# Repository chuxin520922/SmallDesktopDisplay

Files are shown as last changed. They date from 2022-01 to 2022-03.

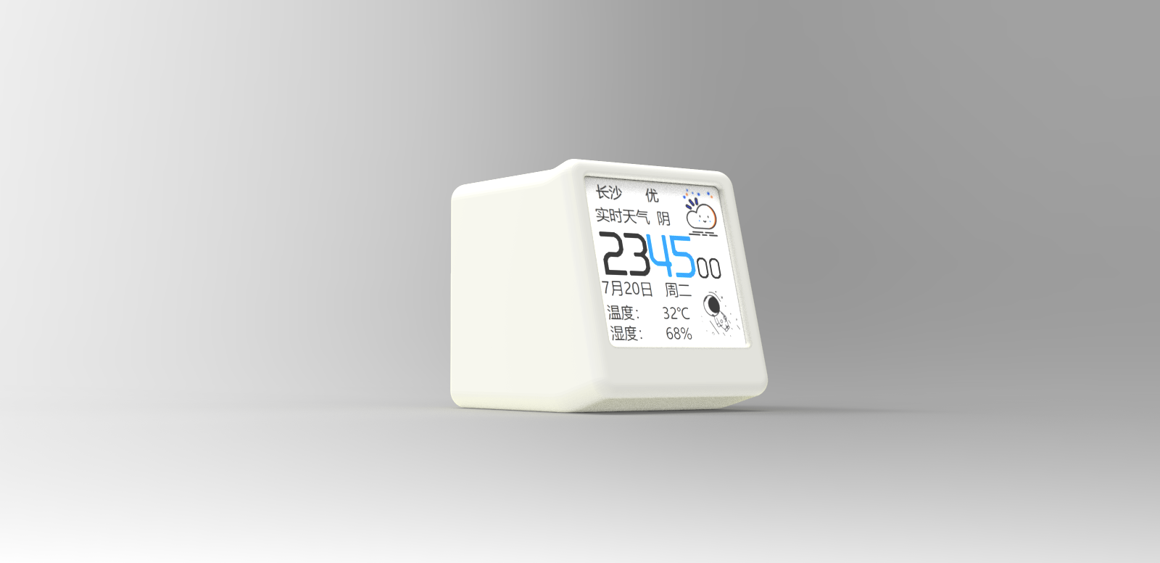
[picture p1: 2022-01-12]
1.Hardware/SD2-推荐桌面摆件/渲染图/渲染图2.png

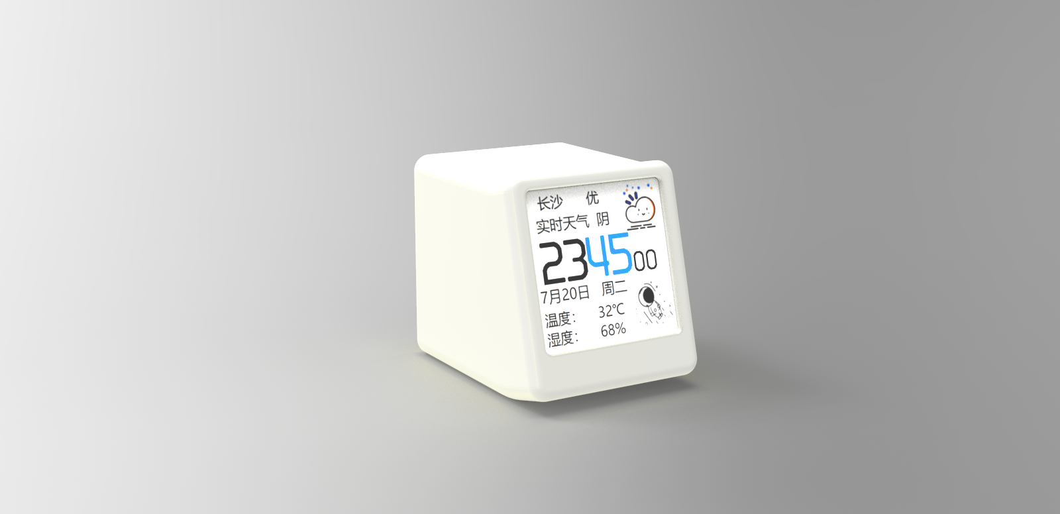
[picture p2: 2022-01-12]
1.Hardware/SD2-推荐桌面摆件/渲染图/渲染图3.png

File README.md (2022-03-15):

# SmallDesktopDisplay
# 沙雕系列-SD -太空人天气时钟显示

**视频介绍：** https://www.bilibili.com/video/BV1V64y1e72M/

## 1. 硬件打样说明

**PCB打样的话暂时没发现有啥需要特别注意的，注意附带的文件下单提示。** PCB文件可以直接拿去工厂打样，两层板很便宜，器件BOM的话也都是比较常用的。

`Hardware`文件内目前包含两个版本的PCB电路：

* **SD2-推荐桌面摆件** ：基于下面的版本轻微修改，将按键删去，无需按键，一键直达编译下载;新增了触摸扩展板，<code>IO口标识需要根据实际连接的改</code>
* **SD3-电脑主机显示** ：即视频中出现的版本，修改了PCB形状以适配新的外壳

**外壳加工** 根据自己喜欢的版本选择，`3D Model`文件夹目前包含2个版本的外壳文件：一 一 对 应文件即可

## 2. 固件编译说明

固件框架主要基于Arduino开发完成，玩过Arduino的基本没有上手难度了，把Firmware/Libraries里面的库安装到Arduino库目录（如果你用的是Arduino IDE的话）即可。

> 由于后续发现，使用的是VS code上面的PlatfromIO插件进行Arduino开发，因为VS code+PlatfromIO编译速度起飞，强烈推荐使用VS code+PlatfromIO来编译，大家可以选择自己喜欢的IDE就好了。
> 

**然后这里需要官方库文件才能正常使用：**

肯定得安装ESP83266的Arduino<code>**支持包2.6.3**</code>（百度也有海量教程，本文件已经附带安装包，直接安装即可）

**代码优化版本：VS code+PlatfromIO** https://github.com/SmallDesktopDisplay-team/SmallDesktopDisplay

## 3. QQ交流群

请注明来意！

官方群1：<code>811058758</code> （已满）

官方群2：<code>887171863</code>（已满）

官方群3：<code>477140920</code>（未满）

## 其他的后续再补充，有用的话记得点星星~

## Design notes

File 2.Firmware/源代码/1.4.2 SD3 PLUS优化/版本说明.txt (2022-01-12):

 * SmallDesktopDisplay
 *    小型桌面显示器
 * 
 * 原  作  者：Misaka
 * 修      改：微车游
 * 讨  论  群：811058758、887171863、720661626
 * 创 建 日 期：2021.07.19
 * 最后更改日期：2021.11.28
 * 更 改 说 明：V1.1添加串口调试，波特率115200\8\n\1；增加版本号显示。
 *            V1.2亮度和城市代码保存到EEPROM，断电可保存
 *            V1.3.1 更改smartconfig改为WEB配网模式，同时在配网的同时增加亮度、屏幕方向设置。
 *            V1.3.2 增加wifi休眠模式，仅在需要连接的情况下开启wifi，其他时间关闭wifi。增加wifi保存至eeprom（目前仅保存一组ssid和密码）
 *            V1.3.3  修改WiFi保存后无法删除的问题。目前更改为使用串口控制，输入 0x05 重置WiFi数据并重启。
 *                    增加web配网以及串口设置天气更新时间的功能。
 *            V1.3.4  修改web配网页面设置，将wifi设置页面以及其余设置选项放入同一页面中。
 *                    增加web页面设置是否使用DHT传感器。（使能DHT后才可使用）
 *             1.4.2  增加长按SD3 Plus底部按钮重置WiFi
 *                    基本汉化网页配置页面
 * 
 * 引 脚 分 配： SCK  GPIO14
 *             MOSI  GPIO13
 *             RES   GPIO2
 *             DC    GPIO0
 *             LCDBL GPIO5
 *             
 *             增加DHT11温湿度传感器，传感器接口为 GPIO 12
 * 
 *    感谢群友 @你别失望  提醒发现WiFi保存后无法重置的问题，目前已解决。详情查看更改说明！

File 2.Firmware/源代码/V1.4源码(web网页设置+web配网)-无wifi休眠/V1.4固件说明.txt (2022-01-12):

 SmallDesktopDisplay
    小型桌面显示器

原  作  者：Misaka
修      改：微车游
 
固件文件说明：
1、固件基本功能包含串口设置、web配网。详细说明请查看各个版本文件中的版本说明文件。
2、V1.4固件暂时只放出bin文件，考虑到可能还有bug。
3、V1.4版本重大更新：增加WEB设置页面，可以通过连接同一wifi下浏览器输入http://sd3.local，即可进行设置。

更 改 说 明：V1.1添加串口调试，波特率115200\8\n\1；增加版本号显示。
 *            V1.2亮度和城市代码保存到EEPROM，断电可保存
 *            V1.3.1 更改smartconfig改为WEB配网模式，同时在配网的同时增加亮度、屏幕方向设置。
 *            V1.3.2 增加wifi休眠模式，仅在需要连接的情况下开启wifi，其他时间关闭wifi。增加wifi保存至eeprom（目前仅保存一组ssid和密码）
 *            V1.3.3  修改WiFi保存后无法删除的问题。目前更改为使用串口控制，输入 0x05 重置WiFi数据并重启。
 *                    增加web配网以及串口设置天气更新时间的功能。
 *            V1.3.4  修改web配网页面设置，将wifi设置页面以及其余设置选项放入同一页面中。
 *                    增加web页面设置是否使用DHT传感器。（使能DHT后才可使用）
 *            V1.4    增加web服务器，使用web网页进行设置。由于使用了web服务器，无法开启WiFi休眠。
	         注意，此版本中的DHT11传感器和太空人图片选择可以通过web网页设置来进行选择，无需通过使能标志来重新编译。

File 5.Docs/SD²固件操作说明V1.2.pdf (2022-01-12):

# --------------- SD²固件操作指南------

# 更新日志：

# V1.0：初始程序 V1.1：增加了串口设置亮度、地址的功能 V1.2：亮度和城市代码保存到 EEPROM，断电可保存

# --------------- SD²固件操作指南------

# 一、 联网设置 1、将设备上电，电源输入规格为 5V； 2、等待联网进度条流过，会出现联网二维码； 3、使用手机微信扫码，扫码前请确认手机已连接至路由器的 2.4G WiFi 网

| 络，（MIUI12 需手动打开位置获取）；

# 4、按手机提示输入 WiFi 密码，点击配网。

# 注：有时候一次连接不成功，请多试几次；第一次联网后时间会大概率显示 不对，断电重启即可。地址根据 IP 地址获得，某些运营商网络可能出现地址 漂移等状况，请手动修改。

# 二、 串口设置(仅适用于 SD²V1.1 以上软件版本) 1、确保电脑已安装 CH340 驱动，打开串口软件； 2、将串口设置为 115200\8\n\1，如图；

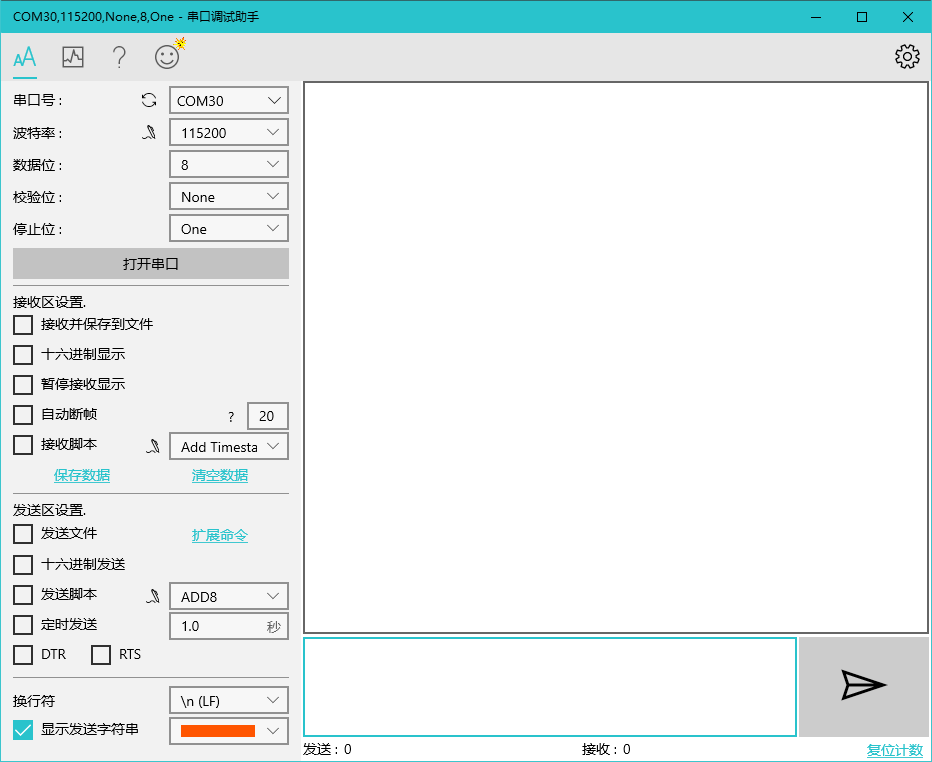
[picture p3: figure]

# 3、点击打开串口； 4、随便发送数据至设备；会回复操作说明，如图； 5、按操作说明输入控制代码即可，如图；

# --------------- SD²固件操作指南------

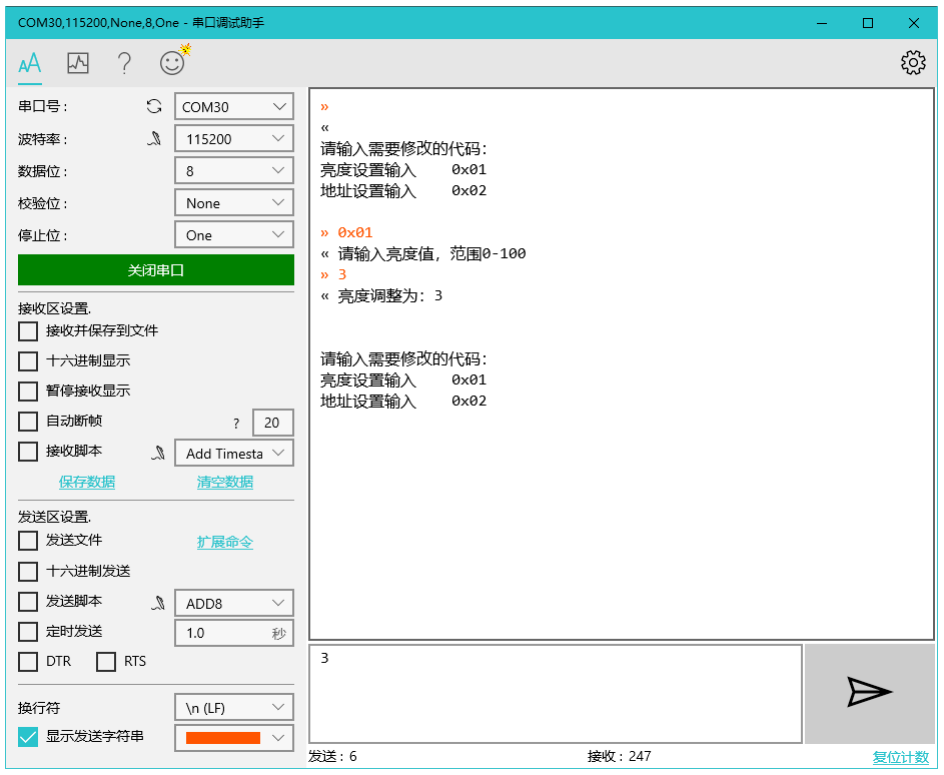
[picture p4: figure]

# 注：城市代码见附件。

# By Misaka

# --------------- SD²固件操作指南------

# 附件：城市代码 Ctrl+F 查找

"北京"=>"101010100","海淀"=>"101010200","朝阳"=>"101010300","顺义"=>"101010400","怀柔"=>"101010500","通州"=>"101010600","昌平

"=>"101010700","延庆"=>"101010800","丰台"=>"101010900","石景山"=>"101011000","大兴"=>"101011100","房山"=>"101011200","密云

"=>"101011300","门头沟"=>"101011400","平谷"=>"101011500","八达岭"=>"101011600","佛爷顶"=>"101011700","汤河口"=>"101011800","密

云上甸子"=>"101011900","斋堂"=>"101012000","霞云岭"=>"101012100",

"上海"=>"101020100","闵行"=>"101020200","宝山"=>"101020300","川沙"=>"101020400","嘉定"=>"101020500","南汇"=>"101020600","金山

"=>"101020700","青浦"=>"101020800","松江"=>"101020900","奉贤"=>"101021000","崇明"=>"101021100","陈家镇"=>"101021101","引水船

"=>"101021102","徐家汇"=>"101021200","浦东"=>"101021300",

"天津"=>"101030100","武清"=>"101030200","宝坻"=>"101030300","东丽"=>"101030400","西青"=>"101030500","北辰"=>"101030600","宁河

"=>"101030700","汉沽"=>"101030800","静海"=>"101030900","津南"=>"101031000","塘沽"=>"101031100","大港"=>"101031200","平台

"=>"101031300","蓟县"=>"101031400",

"重庆"=>"101040100","永川"=>"101040200","合川"=>"101040300","南川"=>"101040400","江津"=>"101040500","万盛"=>"101040600","渝北

"=>"101040700","北碚"=>"101040800","巴南"=>"101040900","长寿"=>"101041000","黔江"=>"101041100","万州天城"=>"101041200","万州龙

宝"=>"101041300","涪陵"=>"101041400","开县"=>"101041500","城口"=>"101041600","云阳"=>"101041700","巫溪"=>"101041800","奉节

"=>"101041900","巫山"=>"101042000","潼南"=>"101042100","垫江"=>"101042200","梁平"=>"101042300","忠县"=>"101042400","石柱

"=>"101042500","大足"=>"101042600","荣昌"=>"101042700","铜梁"=>"101042800","璧山"=>"101042900","丰都"=>"101043000","武隆

"=>"101043100","彭水"=>"101043200","綦江"=>"101043300","酉阳"=>"101043400","金佛山"=>"101043500","秀山"=>"101043600","沙坪坝

"=>"101043700",

"哈尔滨"=>"101050101","双城"=>"101050102","呼兰"=>"101050103","阿城"=>"101050104","宾县"=>"101050105","依兰"=>"101050106","巴彦

"=>"101050107","通河"=>"101050108","方正"=>"101050109","延寿"=>"101050110","尚志"=>"101050111","五常"=>"101050112","木兰

"=>"101050113","齐齐哈尔"=>"101050201","讷河"=>"101050202","龙江"=>"101050203","甘南"=>"101050204","富裕"=>"101050205","依安

"=>"101050206","拜泉"=>"101050207","克山"=>"101050208","克东"=>"101050209","泰来"=>"101050210","牡丹江"=>"101050301","海林

"=>"101050302","穆棱"=>"101050303","林口"=>"101050304","绥芬河"=>"101050305","宁安"=>"101050306","东宁"=>"101050307","佳木斯

"=>"101050401","汤原"=>"101050402","抚远"=>"101050403","桦川"=>"101050404","桦南"=>"101050405","同江"=>"101050406","富锦

"=>"101050407","绥化"=>"101050501","肇东"=>"101050502","安达"=>"101050503","海伦"=>"101050504","明水"=>"101050505","望奎

"=>"101050506","兰西"=>"101050507","青冈"=>"101050508","庆安"=>"101050509","绥棱"=>"101050510","黑河"=>"101050601","嫩江

"=>"101050602","孙吴"=>"101050603","逊克"=>"101050604","五大连池"=>"101050605","北安"=>"101050606","大兴安岭"=>"101050701","塔

河"=>"101050702","漠河"=>"101050703","呼玛"=>"101050704","呼中"=>"101050705","新林"=>"101050706","阿木尔"=>"101050707","加格达

奇"=>"101050708","伊春"=>"101050801","乌伊岭"=>"101050802","五营"=>"101050803","铁力"=>"101050804","嘉荫"=>"101050805","大庆

"=>"101050901","林甸"=>"101050902","肇州"=>"101050903","肇源"=>"101050904","杜蒙"=>"101050905","七台河"=>"101051002","勃利

"=>"101051003","鸡西"=>"101051101","虎林"=>"101051102","密山"=>"101051103","鸡东"=>"101051104","鹤岗"=>"101051201","绥滨

"=>"101051202","萝北"=>"101051203","双鸭山"=>"101051301","集贤"=>"101051302","宝清"=>"101051303","饶河"=>"101051304",

"长春"=>"101060101","农安"=>"101060102","德惠"=>"101060103","九台"=>"101060104","榆树"=>"101060105","双阳"=>"101060106","吉林

"=>"101060201","舒兰"=>"101060202","永吉"=>"101060203","蛟河"=>"101060204","磐石"=>"101060205","桦甸"=>"101060206","烟筒山

"=>"101060207","延吉"=>"101060301","敦化"=>"101060302","安图"=>"101060303","汪清"=>"101060304","和龙"=>"101060305","天池

# --------------- SD²固件操作指南------

"=>"101060306","龙井"=>"101060307","珲春"=>"101060308","图们"=>"101060309","松江"=>"101060310","罗子沟"=>"101060311","延边

"=>"101060312","四平"=>"101060401","双辽"=>"101060402","梨树"=>"101060403","公主岭"=>"101060404","伊通"=>"101060405","孤家子

"=>"101060406","通化"=>"101060501","梅河口"=>"101060502","柳河"=>"101060503","辉南"=>"101060504","集安"=>"101060505","通化县

"=>"101060506","白城"=>"101060601","洮南"=>"101060602","大安"=>"101060603","镇赉"=>"101060604","通榆"=>"101060605","辽源

"=>"101060701","东丰"=>"101060702","松原"=>"101060801","乾安"=>"101060802","前郭"=>"101060803","长岭"=>"101060804","扶余

"=>"101060805","白山"=>"101060901","靖宇"=>"101060902","临江"=>"101060903","东岗"=>"101060904","长白"=>"101060905",

"沈阳"=>"101070101","苏家屯"=>"101070102","辽中"=>"101070103","康平"=>"101070104","法库"=>"101070105","新民"=>"101070106","于洪

"=>"101070107","新城子"=>"101070108","大连"=>"101070201","瓦房店"=>"101070202","金州"=>"101070203","普兰店"=>"101070204","旅顺

"=>"101070205","长海"=>"101070206","庄河"=>"101070207","皮口"=>"101070208","海洋岛"=>"101070209","鞍山"=>"101070301","台安

"=>"101070302","岫岩"=>"101070303","海城"=>"101070304","抚顺"=>"101070401","清原"=>"101070403","章党"=>"101070404","本溪

"=>"101070501","本溪县"=>"101070502","草河口"=>"101070503","桓仁"=>"101070504","丹东"=>"101070601","凤城"=>"101070602","宽甸

"=>"101070603","东港"=>"101070604","东沟"=>"101070605","锦州"=>"101070701","凌海"=>"101070702","北宁"=>"101070703","义县

"=>"101070704","黑山"=>"101070705","北镇"=>"101070706","营口"=>"101070801","大石桥"=>"101070802","盖州"=>"101070803","阜新

"=>"101070901","彰武"=>"101070902","辽阳"=>"101071001","辽阳县"=>"101071002","灯塔"=>"101071003","铁岭"=>"101071101","开原

"=>"101071102","昌图"=>"101071103","西丰"=>"101071104","朝阳"=>"101071201","建平"=>"101071202","凌源"=>"101071203","喀左

"=>"101071204","北票"=>"101071205","羊山"=>"101071206","建平县"=>"101071207","盘锦"=>"101071301","大洼"=>"101071302","盘山

"=>"101071303","葫芦岛"=>"101071401","建昌"=>"101071402","绥中"=>"101071403","兴城"=>"101071404",

"呼和浩特"=>"101080101","土默特左旗"=>"101080102","托克托"=>"101080103","和林格尔"=>"101080104","清水河"=>"101080105","呼和浩特

市郊区"=>"101080106","武川"=>"101080107","包头"=>"101080201","白云鄂博"=>"101080202","满都拉"=>"101080203","土默特右旗

"=>"101080204","固阳"=>"101080205","达尔罕茂明安联合旗"=>"101080206","石拐"=>"101080207","乌海"=>"101080301","集宁

"=>"101080401","卓资"=>"101080402","化德"=>"101080403","商都"=>"101080404","希拉穆仁"=>"101080405","兴和"=>"101080406","凉城

"=>"101080407","察哈尔右翼前旗"=>"101080408","察哈尔右翼中旗"=>"101080409","察哈尔右翼后旗"=>"101080410","四子王旗

"=>"101080411","丰镇"=>"101080412","通辽"=>"101080501","舍伯吐"=>"101080502","科尔沁左翼中旗"=>"101080503","科尔沁左翼后旗

"=>"101080504","青龙山"=>"101080505","开鲁"=>"101080506","库伦旗"=>"101080507","奈曼旗"=>"101080508","扎鲁特旗"=>"101080509","

高力板"=>"101080510","巴雅尔吐胡硕"=>"101080511","通辽钱家店"=>"101080512","赤峰"=>"101080601","赤峰郊区站"=>"101080602","阿鲁

科尔沁旗"=>"101080603","浩尔吐"=>"101080604","巴林左旗"=>"101080605","巴林右旗"=>"101080606","林西"=>"101080607","克什克腾旗

"=>"101080608","翁牛特旗"=>"101080609","岗子"=>"101080610","喀喇沁旗"=>"101080611","八里罕"=>"101080612","宁城"=>"101080613","

敖汉旗"=>"101080614","宝过图"=>"101080615","鄂尔多斯"=>"101080701","达拉特旗"=>"101080703","准格尔旗"=>"101080704","鄂托克前旗

"=>"101080705","河南"=>"101080706","伊克乌素"=>"101080707","鄂托克旗"=>"101080708","杭锦旗"=>"101080709","乌审旗

"=>"101080710","伊金霍洛旗"=>"101080711","乌审召"=>"101080712","东胜"=>"101080713","临河"=>"101080801","五原"=>"101080802","磴

口"=>"101080803","乌拉特前旗"=>"101080804","大佘太"=>"101080805","乌拉特中旗"=>"101080806","乌拉特后旗"=>"101080807","海力素

"=>"101080808","那仁宝力格"=>"101080809","杭锦后旗"=>"101080810","巴盟农试站"=>"101080811","锡林浩特"=>"101080901","朝克乌拉

"=>"101080902","二连浩特"=>"101080903","阿巴嘎旗"=>"101080904","伊和郭勒"=>"101080905","苏尼特左旗"=>"101080906","苏尼特右旗

"=>"101080907","朱日和"=>"101080908","东乌珠穆沁旗"=>"101080909","西乌珠穆沁旗"=>"101080910","太仆寺旗"=>"101080911","镶黄旗

"=>"101080912","正镶白旗"=>"101080913","正兰旗"=>"101080914","多伦"=>"101080915","博克图"=>"101080916","乌拉盖"=>"101080917","

白日乌拉"=>"101080918","那日图"=>"101080919","呼伦贝尔"=>"101081000","海拉尔"=>"101081001","小二沟"=>"101081002","阿荣旗

"=>"101081003","莫力达瓦旗"=>"101081004","鄂伦春旗"=>"101081005","鄂温克旗"=>"101081006","陈巴尔虎旗"=>"101081007","新巴尔虎左

旗"=>"101081008","新巴尔虎右旗"=>"101081009","满洲里"=>"101081010","牙克石"=>"101081011","扎兰屯"=>"101081012","额尔古纳

"=>"101081014","根河"=>"101081015","图里河"=>"101081016","乌兰浩特"=>"101081101","阿尔山"=>"101081102","科尔沁右翼中旗

# --------------- SD²固件操作指南------

"=>"101081103","胡尔勒"=>"101081104","扎赉特旗"=>"101081105","索伦"=>"101081106","突泉"=>"101081107","霍林郭勒"=>"101081108","

阿拉善左旗"=>"101081201","阿拉善右旗"=>"101081202","额济纳旗"=>"101081203","拐子湖"=>"101081204","吉兰太"=>"101081205","锡林高

勒"=>"101081206","头道湖"=>"101081207","中泉子"=>"101081208","巴彦诺尔贡"=>"101081209","雅布赖"=>"101081210","乌斯太

"=>"101081211","孪井滩"=>"101081212",

"石家庄"=>"101090101","井陉"=>"101090102","正定"=>"101090103","栾城"=>"101090104","行唐"=>"101090105","灵寿"=>"101090106","高邑

"=>"101090107","深泽"=>"101090108","赞皇"=>"101090109","无极"=>"101090110","平山"=>"101090111","元氏"=>"101090112","赵县

"=>"101090113","辛集"=>"101090114","藁城"=>"101090115","晋洲"=>"101090116","新乐"=>"101090117","保定"=>"101090201","满城

"=>"101090202","阜平"=>"101090203","徐水"=>"101090204","唐县"=>"101090205","高阳"=>"101090206","容城"=>"101090207","紫荆关

"=>"101090208","涞源"=>"101090209","望都"=>"101090210","安新"=>"101090211","易县"=>"101090212","涞水"=>"101090213","曲阳

"=>"101090214","蠡县"=>"101090215","顺平"=>"101090216","雄县"=>"101090217","涿州"=>"101090218","定州"=>"101090219","安国

"=>"101090220","高碑店"=>"101090221","张家口"=>"101090301","宣化"=>"101090302","张北"=>"101090303","康保"=>"101090304","沽源

"=>"101090305","尚义"=>"101090306","蔚县"=>"101090307","阳原"=>"101090308","怀安"=>"101090309","万全"=>"101090310","怀来

"=>"101090311","涿鹿"=>"101090312","赤城"=>"101090313","崇礼"=>"101090314","承德"=>"101090402","承德县"=>"101090403","兴隆

"=>"101090404","平泉"=>"101090405","滦平"=>"101090406","隆化"=>"101090407","丰宁"=>"101090408","宽城"=>"101090409","围场

"=>"101090410","塞罕坎"=>"101090411","唐山"=>"101090501","丰南"=>"101090502","丰润"=>"101090503","滦县"=>"101090504","滦南

"=>"101090505","乐亭"=>"101090506","迁西"=>"101090507","玉田"=>"101090508","唐海"=>"101090509","遵化"=>"101090510","迁安

"=>"101090511","廊坊"=>"101090601","固安"=>"101090602","永清"=>"101090603","香河"=>"101090604","大城"=>"101090605","文安

"=>"101090606","大厂"=>"101090607","霸州"=>"101090608","三河"=>"101090609","沧州"=>"101090701","青县"=>"101090702","东光

"=>"101090703","海兴"=>"101090704","盐山"=>"101090705","肃宁"=>"101090706","南皮"=>"101090707","吴桥"=>"101090708","献县

"=>"101090709","孟村"=>"101090710","泊头"=>"101090711","任丘"=>"101090712","黄骅"=>"101090713","河间"=>"101090714","曹妃甸

"=>"101090715","衡水"=>"101090801","枣强"=>"101090802","武邑"=>"101090803","武强"=>"101090804","饶阳"=>"101090805","安平

"=>"101090806","故城"=>"101090807","景县"=>"101090808","阜城"=>"101090809","冀州"=>"101090810","深州"=>"101090811","邢台

"=>"101090901","临城"=>"101090902","邢台县浆水"=>"101090903","内邱"=>"101090904","柏乡"=>"101090905","隆尧"=>"101090906","南和

"=>"101090907","宁晋"=>"101090908","巨鹿"=>"101090909","新河"=>"101090910","广宗"=>"101090911","平乡"=>"101090912","威县

"=>"101090913","清河"=>"101090914","临西"=>"101090915","南宫"=>"101090916","沙河"=>"101090917","任县"=>"101090918","邯郸

"=>"101091001","峰峰"=>"101091002","临漳"=>"101091003","成安"=>"101091004","大名"=>"101091005","涉县"=>"101091006","磁县

"=>"101091007","肥乡"=>"101091008","永年"=>"101091009","邱县"=>"101091010","鸡泽"=>"101091011","广平"=>"101091012","馆陶

"=>"101091013","魏县"=>"101091014","曲周"=>"101091015","武安"=>"101091016","秦皇岛"=>"101091101","青龙"=>"101091102","昌黎

"=>"101091103","抚宁"=>"101091104","卢龙"=>"101091105","北戴河"=>"101091106",

"太原"=>"101100101","清徐"=>"101100102","阳曲"=>"101100103","娄烦"=>"101100104","太原古交区"=>"101100105","太原北郊

"=>"101100106","太原南郊"=>"101100107","大同"=>"101100201","阳高"=>"101100202","大同县"=>"101100203","天镇"=>"101100204","广灵

"=>"101100205","灵邱"=>"101100206","浑源"=>"101100207","左云"=>"101100208","阳泉"=>"101100301","盂县"=>"101100302","平定

"=>"101100303","晋中"=>"101100401","榆次"=>"101100402","榆社"=>"101100403","左权"=>"101100404","和顺"=>"101100405","昔阳

"=>"101100406","寿阳"=>"101100407","太谷"=>"101100408","祁县"=>"101100409","平遥"=>"101100410","灵石"=>"101100411","介休

"=>"101100412","长治"=>"101100501","黎城"=>"101100502","屯留"=>"101100503","潞城"=>"101100504","襄垣"=>"101100505","平顺

"=>"101100506","武乡"=>"101100507","沁县"=>"101100508","长子"=>"101100509","沁源"=>"101100510","壶关"=>"101100511","晋城

"=>"101100601","沁水"=>"101100602","阳城"=>"101100603","陵川"=>"101100604","高平"=>"101100605","临汾"=>"101100701","曲沃

"=>"101100702","永和"=>"101100703","隰县"=>"101100704","大宁"=>"101100705","吉县"=>"101100706","襄汾"=>"101100707","蒲县

"=>"101100708","汾西"=>"101100709","洪洞"=>"101100710","霍州"=>"101100711","乡宁"=>"101100712","翼城"=>"101100713","侯马

# --------------- SD²固件操作指南------

"=>"101100714","浮山"=>"101100715","安泽"=>"101100716","古县"=>"101100717","运城"=>"101100801","临猗"=>"101100802","稷山

"=>"101100803","万荣"=>"101100804","河津"=>"101100805","新绛"=>"101100806","绛县"=>"101100807","闻喜"=>"101100808","垣曲

"=>"101100809","永济"=>"101100810","芮城"=>"101100811","夏县"=>"101100812","平陆"=>"101100813","朔州"=>"101100901","平鲁

"=>"101100902","山阴"=>"101100903","右玉"=>"101100904","应县"=>"101100905","怀仁"=>"101100906","忻州"=>"101101001","定襄

"=>"101101002","五台县豆村"=>"101101003","河曲"=>"101101004","偏关"=>"101101005","神池"=>"101101006","宁武"=>"101101007","代县

"=>"101101008","繁峙"=>"101101009","五台山"=>"101101010","保德"=>"101101011","静乐"=>"101101012","岢岚"=>"101101013","五寨

"=>"101101014","原平"=>"101101015","吕梁"=>"101101100","离石"=>"101101101","临县"=>"101101102","兴县"=>"101101103","岚县

"=>"101101104","柳林"=>"101101105","石楼"=>"101101106","方山"=>"101101107","交口"=>"101101108","中阳"=>"101101109","孝义

"=>"101101110","汾阳"=>"101101111","文水"=>"101101112","交城"=>"101101113",

"西安"=>"101110101","长安"=>"101110102","临潼"=>"101110103","蓝田"=>"101110104","周至"=>"101110105","户县"=>"101110106","高陵

"=>"101110107","杨凌"=>"101110108","咸阳"=>"101110200","三原"=>"101110201","礼泉"=>"101110202","永寿"=>"101110203","淳化

"=>"101110204","泾阳"=>"101110205","武功"=>"101110206","乾县"=>"101110207","彬县"=>"101110208","长武"=>"101110209","旬邑

"=>"101110210","兴平"=>"101110211","延安"=>"101110300","延长"=>"101110301","延川"=>"101110302","子长"=>"101110303","宜川

"=>"101110304","富县"=>"101110305","志丹"=>"101110306","安塞"=>"101110307","甘泉"=>"101110308","洛川"=>"101110309","黄陵

"=>"101110310","黄龙"=>"101110311","吴起"=>"101110312","榆林"=>"101110401","府谷"=>"101110402","神木"=>"101110403","佳县

"=>"101110404","定边"=>"101110405","靖边"=>"101110406","横山"=>"101110407","米脂"=>"101110408","子洲"=>"101110409","绥德

"=>"101110410","吴堡"=>"101110411","清涧"=>"101110412","渭南"=>"101110501","华县"=>"101110502","潼关"=>"101110503","大荔

"=>"101110504","白水"=>"101110505","富平"=>"101110506","蒲城"=>"101110507","澄城"=>"101110508","合阳"=>"101110509","韩城

"=>"101110510","华阴"=>"101110511","华山"=>"101110512","商洛"=>"101110601","洛南"=>"101110602","柞水"=>"101110603","镇安

"=>"101110605","丹凤"=>"101110606","商南"=>"101110607","山阳"=>"101110608","安康"=>"101110701","紫阳"=>"101110702","石泉

"=>"101110703","汉阴"=>"101110704","旬阳"=>"101110705","岚皋"=>"101110706","平利"=>"101110707","白河"=>"101110708","镇坪

"=>"101110709","宁陕"=>"101110710","汉中"=>"101110801","略阳"=>"101110802","勉县"=>"101110803","留坝"=>"101110804","洋县

"=>"101110805","城固"=>"101110806","西乡"=>"101110807","佛坪"=>"101110808","宁强"=>"101110809","南郑"=>"101110810","镇巴

"=>"101110811","宝鸡"=>"101110901","宝鸡县"=>"101110902","千阳"=>"101110903","麟游"=>"101110904","岐山"=>"101110905","凤翔

"=>"101110906","扶风"=>"101110907","眉县"=>"101110908","太白"=>"101110909","凤县"=>"101110910","陇县"=>"101110911","铜川

"=>"101111001","耀县"=>"101111002","宜君"=>"101111003",

"济南"=>"101120101","长清"=>"101120102","商河"=>"101120103","章丘"=>"101120104","平阴"=>"101120105","济阳"=>"101120106","青岛

"=>"101120201","崂山"=>"101120202","潮连岛"=>"101120203","即墨"=>"101120204","胶州"=>"101120205","胶南"=>"101120206","莱西

"=>"101120207","平度"=>"101120208","淄博"=>"101120301","淄川"=>"101120302","博山"=>"101120303","高青"=>"101120304","周村

"=>"101120305","沂源"=>"101120306","桓台"=>"101120307","临淄"=>"101120308","德州"=>"101120401","武城"=>"101120402","临邑

"=>"101120403","陵县"=>"101120404","齐河"=>"101120405","乐陵"=>"101120406","庆云"=>"101120407","平原"=>"101120408","宁津

"=>"101120409","夏津"=>"101120410","禹城"=>"101120411","烟台"=>"101120501","莱州"=>"101120502","长岛"=>"101120503","蓬莱

"=>"101120504","龙口"=>"101120505","招远"=>"101120506","栖霞"=>"101120507","福山"=>"101120508","牟平"=>"101120509","莱阳

"=>"101120510","海阳"=>"101120511","千里岩"=>"101120512","潍坊"=>"101120601","青州"=>"101120602","寿光"=>"101120603","临朐

"=>"101120604","昌乐"=>"101120605","昌邑"=>"101120606","安丘"=>"101120607","高密"=>"101120608","诸城"=>"101120609","济宁

"=>"101120701","嘉祥"=>"101120702","微山"=>"101120703",

"鱼台"=>"101120704","兖州"=>"101120705","金乡"=>"101120706","汶上"=>"101120707","泗水"=>"101120708","梁山"=>"101120709","曲阜

"=>"101120710","邹城"=>"101120711","泰安"=>"101120801","新泰"=>"101120802","泰山"=>"101120803","肥城"=>"101120804","东平

"=>"101120805","宁阳"=>"101120806","临沂"=>"101120901","莒南"=>"101120902","沂南"=>"101120903","苍山"=>"101120904","临沭

# --------------- SD²固件操作指南------

"=>"101120905","郯城"=>"101120906","蒙阴"=>"101120907","平邑"=>"101120908","费县"=>"101120909","沂水"=>"101120910","马站

"=>"101120911","菏泽"=>"101121001","鄄城"=>"101121002","郓城"=>"101121003","东明"=>"101121004","定陶"=>"101121005","巨野

"=>"101121006","曹县"=>"101121007","成武"=>"101121008","单县"=>"101121009","滨州"=>"101121101","博兴"=>"101121102","无棣

"=>"101121103","阳信"=>"101121104","惠民"=>"101121105","沾化"=>"101121106","邹平"=>"101121107","东营"=>"101121201","河口

"=>"101121202","垦利"=>"101121203","利津"=>"101121204","广饶"=>"101121205","威海"=>"101121301","文登"=>"101121302","荣成

"=>"101121303","乳山"=>"101121304","成山头"=>"101121305","石岛"=>"101121306","枣庄"=>"101121401","薛城"=>"101121402","峄城

"=>"101121403","台儿庄"=>"101121404","滕州"=>"101121405","日照"=>"101121501","五莲"=>"101121502","莒县"=>"101121503","莱芜

"=>"101121601","聊城"=>"101121701","冠县"=>"101121702","阳谷"=>"101121703","高唐"=>"101121704","茌平"=>"101121705","东阿

"=>"101121706","临清"=>"101121707","朝城"=>"101121708","莘县"=>"101121709",

"乌鲁木齐"=>"101130101","蔡家湖"=>"101130102","小渠子"=>"101130103","巴仑台"=>"101130104","达坂城"=>"101130105","十三间房气象站

"=>"101130106","天山大西沟"=>"101130107","乌鲁木齐牧试站"=>"101130108","天池"=>"101130109","白杨沟"=>"101130110","克拉玛依

"=>"101130201","石河子"=>"101130301","炮台"=>"101130302","莫索湾"=>"101130303","乌兰乌苏"=>"101130304","昌吉"=>"101130401","呼

图壁"=>"101130402","米泉"=>"101130403","阜康"=>"101130404","吉木萨尔"=>"101130405","奇台"=>"101130406","玛纳斯"=>"101130407","

木垒"=>"101130408","北塔山"=>"101130409","吐鲁番"=>"101130501","托克逊"=>"101130502","吐鲁番东坎"=>"101130503","鄯善

"=>"101130504","红柳河"=>"101130505","库尔勒"=>"101130601","轮台"=>"101130602","尉犁"=>"101130603","若羌"=>"101130604","且末

"=>"101130605","和静"=>"101130606","焉耆"=>"101130607","和硕"=>"101130608","库米什"=>"101130609","巴音布鲁克"=>"101130610","铁

干里克"=>"101130611","博湖"=>"101130612","塔中"=>"101130613","阿拉尔"=>"101130701","阿克苏"=>"101130801","乌什"=>"101130802","

温宿"=>"101130803","拜城"=>"101130804","新和"=>"101130805","沙雅"=>"101130806","库车"=>"101130807","柯坪"=>"101130808","阿瓦提

"=>"101130809","喀什"=>"101130901","英吉沙"=>"101130902","塔什库尔干"=>"101130903","麦盖提"=>"101130904","莎车"=>"101130905","

叶城"=>"101130906","泽普"=>"101130907","巴楚"=>"101130908","岳普湖"=>"101130909","伽师"=>"101130910","伊宁"=>"101131001","察布

查尔"=>"101131002","尼勒克"=>"101131003","伊宁县"=>"101131004","巩留"=>"101131005","新源"=>"101131006","昭苏"=>"101131007","特

克斯"=>"101131008","霍城"=>"101131009","霍尔果斯"=>"101131010","塔城"=>"101131101","裕民"=>"101131102","额敏"=>"101131103","和

布克赛尔"=>"101131104","托里"=>"101131105","乌苏"=>"101131106","沙湾"=>"101131107","和丰"=>"101131108","哈密"=>"101131201","沁

城"=>"101131202","巴里坤"=>"101131203","伊吾"=>"101131204","淖毛湖"=>"101131205","和田"=>"101131301","皮山"=>"101131302","策勒

"=>"101131303","墨玉"=>"101131304","洛浦"=>"101131305","民丰"=>"101131306","于田"=>"101131307","阿勒泰"=>"101131401","哈巴河

"=>"101131402","一八五团"=>"101131403","黑山头"=>"101131404","吉木乃"=>"101131405","布尔津"=>"101131406","福海"=>"101131407","

富蕴"=>"101131408","青河"=>"101131409","安德河"=>"101131410","阿图什"=>"101131501","乌恰"=>"101131502","阿克陶"=>"101131503","

阿合奇"=>"101131504","吐尔尕特"=>"101131505","博乐"=>"101131601","温泉"=>"101131602","精河"=>"101131603","阿拉山口

"=>"101131606",

"拉萨"=>"101140101","当雄"=>"101140102","尼木"=>"101140103","墨竹贡卡"=>"101140104","日喀则"=>"101140201","拉孜"=>"101140202","

南木林"=>"101140203","聂拉木"=>"101140204","定日"=>"101140205","江孜"=>"101140206","帕里"=>"101140207","山南"=>"101140301","贡

嘎"=>"101140302","琼结"=>"101140303","加查"=>"101140304","浪卡子"=>"101140305","错那"=>"101140306","隆子"=>"101140307","泽当

"=>"101140308","林芝"=>"101140401","波密"=>"101140402","米林"=>"101140403","察隅"=>"101140404","昌都"=>"101140501","丁青

"=>"101140502","类乌齐"=>"101140503","洛隆"=>"101140504","左贡"=>"101140505","芒康"=>"101140506","八宿"=>"101140507","那曲

"=>"101140601","嘉黎"=>"101140603","班戈"=>"101140604","安多"=>"101140605","索县"=>"101140606","比如"=>"101140607","阿里

"=>"101140701","改则"=>"101140702","申扎"=>"101140703","狮泉河"=>"101140704","普兰"=>"101140705",

"西宁"=>"101150101","大通"=>"101150102","湟源"=>"101150103","湟中"=>"101150104","铁卜加"=>"101150105","铁卜加寺"=>"101150106","

中心站"=>"101150107","海东"=>"101150201","乐都"=>"101150202","民和"=>"101150203","互助"=>"101150204","化隆"=>"101150205","循化

# --------------- SD²固件操作指南------

"=>"101150206","冷湖"=>"101150207","平安"=>"101150208","黄南"=>"101150301","尖扎"=>"101150302","泽库"=>"101150303","河南

"=>"101150304","海南"=>"101150401","江西沟"=>"101150402","贵德"=>"101150404","河卡"=>"101150405","兴海"=>"101150406","贵南

"=>"101150407","同德"=>"101150408","共和"=>"101150409","果洛"=>"101150501","班玛"=>"101150502","甘德"=>"101150503","达日

"=>"101150504","久治"=>"101150505","玛多"=>"101150506","清水河"=>"101150507","玛沁"=>"101150508","玉树"=>"101150601","托托河

"=>"101150602","治多"=>"101150603","杂多"=>"101150604","囊谦"=>"101150605","曲麻莱"=>"101150606","海西"=>"101150701","格尔木

"=>"101150702","察尔汉"=>"101150703","野牛沟"=>"101150704","五道梁"=>"101150705","小灶火"=>"101150706","天峻"=>"101150708","乌

兰"=>"101150709","都兰"=>"101150710","诺木洪"=>"101150711","茫崖"=>"101150712","大柴旦"=>"101150713","茶卡"=>"101150714","香日

德"=>"101150715","德令哈"=>"101150716","海北"=>"101150801","门源"=>"101150802","祁连"=>"101150803","海晏"=>"101150804","托勒

"=>"101150805","刚察"=>"101150806",

"兰州"=>"101160101","皋兰"=>"101160102","永登"=>"101160103","榆中"=>"101160104","定西"=>"101160201","通渭"=>"101160202","陇西

"=>"101160203","渭源"=>"101160204","临洮"=>"101160205","漳县"=>"101160206","岷县"=>"101160207","安定"=>"101160208","平凉

"=>"101160301","泾川"=>"101160302","灵台"=>"101160303","崇信"=>"101160304","华亭"=>"101160305","庄浪"=>"101160306","静宁

"=>"101160307","崆峒"=>"101160308","庆阳"=>"101160401","西峰"=>"101160402","环县"=>"101160403","华池"=>"101160404","合水

"=>"101160405","正宁"=>"101160406","宁县"=>"101160407","镇原"=>"101160408","庆城"=>"101160409","武威"=>"101160501","民勤

"=>"101160502","古浪"=>"101160503","乌鞘岭"=>"101160504","天祝"=>"101160505","金昌"=>"101160601","永昌"=>"101160602","张掖

"=>"101160701","肃南"=>"101160702","民乐"=>"101160703","临泽"=>"101160704","高台"=>"101160705","山丹"=>"101160706","酒泉

"=>"101160801","鼎新"=>"101160802","金塔"=>"101160803","马鬃山"=>"101160804","瓜州"=>"101160805","肃北"=>"101160806","玉门镇

"=>"101160807","敦煌"=>"101160808","天水"=>"101160901","北道区"=>"101160902","清水"=>"101160903","秦安"=>"101160904","甘谷

"=>"101160905","武山"=>"101160906","张家川"=>"101160907","麦积"=>"101160908","武都"=>"101161001","成县"=>"101161002","文县

"=>"101161003","宕昌"=>"101161004","康县"=>"101161005","西和"=>"101161006","礼县"=>"101161007","徽县"=>"101161008","两当

"=>"101161009","临夏"=>"101161101","康乐"=>"101161102","永靖"=>"101161103","广河"=>"101161104","和政"=>"101161105","东乡

"=>"101161106","合作"=>"101161201","临潭"=>"101161202","卓尼"=>"101161203","舟曲"=>"101161204","迭部"=>"101161205","玛曲

"=>"101161206","碌曲"=>"101161207","夏河"=>"101161208","白银"=>"101161301","靖远"=>"101161302","会宁"=>"101161303","华家岭

"=>"101161304","景泰"=>"101161305",

"银川"=>"101170101","永宁"=>"101170102","灵武"=>"101170103","贺兰"=>"101170104","石嘴山"=>"101170201","惠农"=>"101170202","平罗

"=>"101170203","陶乐"=>"101170204","石炭井"=>"101170205","大武口"=>"101170206","吴忠"=>"101170301","同心"=>"101170302","盐池

"=>"101170303","韦州"=>"101170304","麻黄山"=>"101170305","青铜峡"=>"101170306","固原"=>"101170401","西吉"=>"101170402","隆德

"=>"101170403","泾源"=>"101170404","六盘山"=>"101170405","彭阳"=>"101170406","中卫"=>"101170501","中宁"=>"101170502","兴仁堡

"=>"101170503","海原"=>"101170504",

"郑州"=>"101180101","巩义"=>"101180102","荥阳"=>"101180103","登封"=>"101180104","新密"=>"101180105","新郑"=>"101180106","中牟

"=>"101180107","郑州农试站"=>"101180108","安阳"=>"101180201","汤阴"=>"101180202","滑县"=>"101180203","内黄"=>"101180204","林州

"=>"101180205","新乡"=>"101180301","获嘉"=>"101180302","原阳"=>"101180303","辉县"=>"101180304","卫辉"=>"101180305","延津

"=>"101180306","封丘"=>"101180307","长垣"=>"101180308","许昌"=>"101180401","鄢陵"=>"101180402","襄城"=>"101180403","长葛

"=>"101180404","禹州"=>"101180405","平顶山"=>"101180501","郏县"=>"101180502","宝丰"=>"101180503","汝州"=>"101180504","叶县

"=>"101180505","舞钢"=>"101180506","鲁山"=>"101180507","信阳"=>"101180601","息县"=>"101180602","罗山"=>"101180603","光山

"=>"101180604","新县"=>"101180605","淮滨"=>"101180606","潢川"=>"101180607","固始"=>"101180608","商城"=>"101180609","鸡公山

"=>"101180610","信阳地区农试站"=>"101180611","南阳"=>"101180701","南召"=>"101180702","方城"=>"101180703","社旗"=>"101180704","

西峡"=>"101180705","内乡"=>"101180706","镇平"=>"101180707","淅川"=>"101180708","新野"=>"101180709","唐河"=>"101180710","邓州

# --------------- SD²固件操作指南------

"=>"101180711","桐柏"=>"101180712","开封"=>"101180801","杞县"=>"101180802","尉氏"=>"101180803","通许"=>"101180804","兰考

"=>"101180805","洛阳"=>"101180901","新安"=>"101180902","孟津"=>"101180903","宜阳"=>"101180904","洛宁"=>"101180905","伊川

"=>"101180906","嵩县"=>"101180907","偃师"=>"101180908","栾川"=>"101180909","汝阳"=>"101180910","商丘"=>"101181001","睢阳区

"=>"101181002","睢县"=>"101181003","民权"=>"101181004","虞城"=>"101181005","柘城"=>"101181006","宁陵"=>"101181007","夏邑

"=>"101181008","永城"=>"101181009","焦作"=>"101181101","修武"=>"101181102","武陟"=>"101181103","沁阳"=>"101181104","博爱

"=>"101181106","温县"=>"101181107","孟州"=>"101181108","鹤壁"=>"101181201","浚县"=>"101181202","淇县"=>"101181203","濮阳

"=>"101181301","台前"=>"101181302","南乐"=>"101181303","清丰"=>"101181304","范县"=>"101181305","周口"=>"101181401","扶沟

"=>"101181402","太康"=>"101181403","淮阳"=>"101181404","西华"=>"101181405","商水"=>"101181406","项城"=>"101181407","郸城

"=>"101181408","鹿邑"=>"101181409","沈丘"=>"101181410","黄泛区"=>"101181411","漯河"=>"101181501","临颍"=>"101181502","舞阳

"=>"101181503","驻马店"=>"101181601","西平"=>"101181602","遂平"=>"101181603","上蔡"=>"101181604","汝南"=>"101181605","泌阳

"=>"101181606","平舆"=>"101181607","新蔡"=>"101181608","确山"=>"101181609","正阳"=>"101181610","三门峡"=>"101181701","灵宝

"=>"101181702","渑池"=>"101181703","卢氏"=>"101181704","济源"=>"101181801",

"南京"=>"101190101","溧水"=>"101190102","高淳"=>"101190103","江宁"=>"101190104","六合"=>"101190105","江浦"=>"101190106","浦口

"=>"101190107","无锡"=>"101190201","江阴"=>"101190202","宜兴"=>"101190203","镇江"=>"101190301","丹阳"=>"101190302","扬中

"=>"101190303","句容"=>"101190304","丹徒"=>"101190305","苏州"=>"101190401","常熟"=>"101190402","张家港"=>"101190403","昆山

"=>"101190404","吴县东山"=>"101190405","吴县"=>"101190406","吴江"=>"101190407","太仓"=>"101190408","南通"=>"101190501","海安

"=>"101190502","如皋"=>"101190503","如东"=>"101190504","吕泗"=>"101190505","吕泗渔场"=>"101190506","启东"=>"101190507","海门

"=>"101190508","通州"=>"101190509","扬州"=>"101190601","宝应"=>"101190602","仪征"=>"101190603","高邮"=>"101190604","江都

"=>"101190605","邗江"=>"101190606","盐城"=>"101190701","响水"=>"101190702","滨海"=>"101190703","阜宁"=>"101190704","射阳

"=>"101190705","建湖"=>"101190706","东台"=>"101190707","大丰"=>"101190708","盐都"=>"101190709","徐州"=>"101190801","徐州农试站

"=>"101190802","丰县"=>"101190803","沛县"=>"101190804","邳州"=>"101190805","睢宁"=>"101190806","新沂"=>"101190807","淮安

"=>"101190901","金湖"=>"101190902","盱眙"=>"101190903","洪泽"=>"101190904","涟水"=>"101190905","淮阴县"=>"101190906","淮阴

"=>"101190907","楚州"=>"101190908","连云港"=>"101191001","东海"=>"101191002","赣榆"=>"101191003","灌云"=>"101191004","灌南

"=>"101191005","西连岛"=>"101191006","燕尾港"=>"101191007","常州"=>"101191101","溧阳"=>"101191102","金坛"=>"101191103","泰州

"=>"101191201","兴化"=>"101191202","泰兴"=>"101191203","姜堰"=>"101191204","靖江"=>"101191205","宿迁"=>"101191301","沭阳

"=>"101191302","泗阳"=>"101191303","泗洪"=>"101191304",

"武汉"=>"101200101","蔡甸"=>"101200102","黄陂"=>"101200103","新洲"=>"101200104","江夏"=>"101200105","襄樊"=>"101200201","襄阳

"=>"101200202","保康"=>"101200203","南漳"=>"101200204","宜城"=>"101200205","老河口"=>"101200206","谷城"=>"101200207","枣阳

"=>"101200208","鄂州"=>"101200301","孝感"=>"101200401","安陆"=>"101200402","云梦"=>"101200403","大悟"=>"101200404","应城

"=>"101200405","汉川"=>"101200406","黄冈"=>"101200501","红安"=>"101200502","麻城"=>"101200503","罗田"=>"101200504","英山

"=>"101200505","浠水"=>"101200506","蕲春"=>"101200507","黄梅"=>"101200508","武穴"=>"101200509","黄石"=>"101200601","大冶

"=>"101200602","阳新"=>"101200603","咸宁"=>"101200701","赤壁"=>"101200702","嘉鱼"=>"101200703","崇阳"=>"101200704","通城

"=>"101200705","通山"=>"101200706","荆州"=>"101200801","江陵"=>"101200802","公安"=>"101200803","石首"=>"101200804","监利

"=>"101200805","洪湖"=>"101200806","松滋"=>"101200807","宜昌"=>"101200901","远安"=>"101200902","秭归"=>"101200903","兴山

"=>"101200904","宜昌县"=>"101200905","五峰"=>"101200906","当阳"=>"101200907","长阳"=>"101200908","宜都"=>"101200909","枝江

"=>"101200910","三峡"=>"101200911","夷陵"=>"101200912","恩施"=>"101201001","利川"=>"101201002","建始"=>"101201003","咸丰

"=>"101201004","宣恩"=>"101201005","鹤峰"=>"101201006","来凤"=>"101201007","巴东"=>"101201008","绿葱坡"=>"101201009","十堰

"=>"101201101","竹溪"=>"101201102","郧西"=>"101201103","郧县"=>"101201104","竹山"=>"101201105","房县"=>"101201106","丹江口

"=>"101201107","神农架"=>"101201201","随州"=>"101201301","广水"=>"101201302","荆门"=>"101201401","钟祥"=>"101201402","京山

# --------------- SD²固件操作指南------

"=>"101201403","天门"=>"101201501","仙桃"=>"101201601","潜江"=>"101201701",

"杭州"=>"101210101","萧山"=>"101210102","桐庐"=>"101210103","淳安"=>"101210104","建德"=>"101210105","余杭"=>"101210106","临安

"=>"101210107","富阳"=>"101210108","湖州"=>"101210201","长兴"=>"101210202","安吉"=>"101210203","德清"=>"101210204","嘉兴

"=>"101210301","嘉善"=>"101210302","海宁"=>"101210303","桐乡"=>"101210304","平湖"=>"101210305","海盐"=>"101210306","宁波

"=>"101210401","慈溪"=>"101210403","余姚"=>"101210404","奉化"=>"101210405","象山"=>"101210406","石浦"=>"101210407","宁海

"=>"101210408","鄞县"=>"101210409","北仑"=>"101210410","鄞州"=>"101210411","镇海"=>"101210412","绍兴"=>"101210501","诸暨

"=>"101210502","上虞"=>"101210503","新昌"=>"101210504","嵊州"=>"101210505","台州"=>"101210601","括苍山"=>"101210602","玉环

"=>"101210603","三门"=>"101210604","天台"=>"101210605","仙居"=>"101210606","温岭"=>"101210607","大陈"=>"101210608","洪家

"=>"101210609","温州"=>"101210701","泰顺"=>"101210702","文成"=>"101210703","平阳"=>"101210704","瑞安"=>"101210705","洞头

"=>"101210706","乐清"=>"101210707","永嘉"=>"101210708","苍南"=>"101210709","丽水"=>"101210801","遂昌"=>"101210802","龙泉

"=>"101210803","缙云"=>"101210804","青田"=>"101210805","云和"=>"101210806","庆元"=>"101210807","金华"=>"101210901","浦江

"=>"101210902","兰溪"=>"101210903","义乌"=>"101210904","东阳"=>"101210905","武义"=>"101210906","永康"=>"101210907","磐安

"=>"101210908","衢州"=>"101211001","常山"=>"101211002","开化"=>"101211003","龙游"=>"101211004","江山"=>"101211005","舟山

"=>"101211101","嵊泗"=>"101211102","嵊山"=>"101211103","岱山"=>"101211104","普陀"=>"101211105","定海"=>"101211106",

"合肥"=>"101220101","长丰"=>"101220102","肥东"=>"101220103","肥西"=>"101220104","蚌埠"=>"101220201","怀远"=>"101220202","固镇

"=>"101220203","五河"=>"101220204","芜湖"=>"101220301","繁昌"=>"101220302","芜湖县"=>"101220303","南陵"=>"101220304","淮南

"=>"101220401","凤台"=>"101220402","马鞍山"=>"101220501","当涂"=>"101220502","安庆"=>"101220601","枞阳"=>"101220602","太湖

"=>"101220603","潜山"=>"101220604","怀宁"=>"101220605","宿松"=>"101220606","望江"=>"101220607","岳西"=>"101220608","桐城

"=>"101220609","宿州"=>"101220701","砀山"=>"101220702","灵璧"=>"101220703","泗县"=>"101220704","萧县"=>"101220705","阜阳

"=>"101220801","阜南"=>"101220802","颍上"=>"101220803","临泉"=>"101220804","界首"=>"101220805","太和"=>"101220806","亳州

"=>"101220901","涡阳"=>"101220902","利辛"=>"101220903","蒙城"=>"101220904","黄山站"=>"101221001","黄山区"=>"101221002","屯溪

"=>"101221003","祁门"=>"101221004","黟县"=>"101221005","歙县"=>"101221006","休宁"=>"101221007","黄山市"=>"101221008","滁州

"=>"101221101","凤阳"=>"101221102","明光"=>"101221103","定远"=>"101221104","全椒"=>"101221105","来安"=>"101221106","天长

"=>"101221107","淮北"=>"101221201","濉溪"=>"101221202","铜陵"=>"101221301","宣城"=>"101221401","泾县"=>"101221402","旌德

"=>"101221403","宁国"=>"101221404","绩溪"=>"101221405","广德"=>"101221406","郎溪"=>"101221407","六安"=>"101221501","霍邱

"=>"101221502","寿县"=>"101221503","南溪"=>"101221504","金寨"=>"101221505","霍山"=>"101221506","舒城"=>"101221507","巢湖

"=>"101221601","庐江"=>"101221602","无为"=>"101221603","含山"=>"101221604","和县"=>"101221605","池州"=>"101221701","东至

"=>"101221702","青阳"=>"101221703","九华山"=>"101221704","石台"=>"101221705",

"福州"=>"101230101","闽清"=>"101230102","闽侯"=>"101230103","罗源"=>"101230104","连江"=>"101230105","马祖"=>"101230106","永泰

"=>"101230107","平潭"=>"101230108","福州郊区"=>"101230109","长乐"=>"101230110","福清"=>"101230111","平潭海峡大桥

"=>"101230112","厦门"=>"101230201","同安"=>"101230202","宁德"=>"101230301","古田"=>"101230302","霞浦"=>"101230303","寿宁

"=>"101230304","周宁"=>"101230305","福安"=>"101230306","柘荣"=>"101230307","福鼎"=>"101230308","屏南"=>"101230309","莆田

"=>"101230401","仙游"=>"101230402","秀屿港"=>"101230403","泉州"=>"101230501","安溪"=>"101230502","九仙山"=>"101230503","永春

"=>"101230504","德化"=>"101230505","南安"=>"101230506","崇武"=>"101230507","金山"=>"101230508","晋江"=>"101230509","漳州

"=>"101230601","长泰"=>"101230602","南靖"=>"101230603","平和"=>"101230604","龙海"=>"101230605","漳浦"=>"101230606","诏安

"=>"101230607","东山"=>"101230608","云霄"=>"101230609","华安"=>"101230610","龙岩"=>"101230701","长汀"=>"101230702","连城

"=>"101230703","武平"=>"101230704","上杭"=>"101230705","永定"=>"101230706","漳平"=>"101230707","三明"=>"101230801","宁化

"=>"101230802","清流"=>"101230803","泰宁"=>"101230804","将乐"=>"101230805","建宁"=>"101230806","明溪"=>"101230807","沙县

# --------------- SD²固件操作指南------

"=>"101230808","尤溪"=>"101230809","永安"=>"101230810","大田"=>"101230811","南平"=>"101230901","顺昌"=>"101230902","光泽

"=>"101230903","邵武"=>"101230904","武夷山"=>"101230905","浦城"=>"101230906","建阳"=>"101230907","松溪"=>"101230908","政和

"=>"101230909","建瓯"=>"101230910",

"南昌"=>"101240101","新建"=>"101240102","南昌县"=>"101240103","安义"=>"101240104","进贤"=>"101240105","莲塘"=>"101240106","九江

"=>"101240201","瑞昌"=>"101240202","庐山"=>"101240203","武宁"=>"101240204","德安"=>"101240205","永修"=>"101240206","湖口

"=>"101240207","彭泽"=>"101240208","星子"=>"101240209","都昌"=>"101240210","棠荫"=>"101240211","修水"=>"101240212","上饶

"=>"101240301","鄱阳"=>"101240302","婺源"=>"101240303","康山"=>"101240304","余干"=>"101240305","万年"=>"101240306","德兴

"=>"101240307","上饶县"=>"101240308","弋阳"=>"101240309","横峰"=>"101240310","铅山"=>"101240311","玉山"=>"101240312","广丰

"=>"101240313","波阳"=>"101240314","抚州"=>"101240401","广昌"=>"101240402","乐安"=>"101240403","崇仁"=>"101240404","金溪

"=>"101240405","资溪"=>"101240406","宜黄"=>"101240407","南城"=>"101240408","南丰"=>"101240409","黎川"=>"101240410","东乡

"=>"101240411","宜春"=>"101240501","铜鼓"=>"101240502","宜丰"=>"101240503","万载"=>"101240504","上高"=>"101240505","靖安

"=>"101240506","奉新"=>"101240507","高安"=>"101240508","樟树"=>"101240509","丰城"=>"101240510","吉安"=>"101240601","吉安县

"=>"101240602","吉水"=>"101240603","新干"=>"101240604","峡江"=>"101240605","永丰"=>"101240606","永新"=>"101240607","井冈山

"=>"101240608","万安"=>"101240609","遂川"=>"101240610","泰和"=>"101240611","安福"=>"101240612","宁冈"=>"101240613","赣州

"=>"101240701","崇义"=>"101240702","上犹"=>"101240703","南康"=>"101240704","大余"=>"101240705","信丰"=>"101240706","宁都

"=>"101240707","石城"=>"101240708","瑞金"=>"101240709","于都"=>"101240710","会昌"=>"101240711","安远"=>"101240712","全南

"=>"101240713","龙南"=>"101240714","定南"=>"101240715","寻乌"=>"101240716","兴国"=>"101240717","景德镇"=>"101240801","乐平

"=>"101240802","萍乡"=>"101240901","莲花"=>"101240902","新余"=>"101241001","分宜"=>"101241002","鹰潭"=>"101241101","余江

"=>"101241102","贵溪"=>"101241103",

"长沙"=>"101250101","宁乡"=>"101250102","浏阳"=>"101250103","马坡岭"=>"101250104","湘潭"=>"101250201","韶山"=>"101250202","湘乡

"=>"101250203","株洲"=>"101250301","攸县"=>"101250302","醴陵"=>"101250303","株洲县"=>"101250304","茶陵"=>"101250305","炎陵

"=>"101250306","衡阳"=>"101250401","衡山"=>"101250402","衡东"=>"101250403","祁东"=>"101250404","衡阳县"=>"101250405","常宁

"=>"101250406","衡南"=>"101250407","耒阳"=>"101250408","南岳"=>"101250409","郴州"=>"101250501","桂阳"=>"101250502","嘉禾

"=>"101250503","宜章"=>"101250504","临武"=>"101250505","桥口"=>"101250506","资兴"=>"101250507","汝城"=>"101250508","安仁

"=>"101250509","永兴"=>"101250510","桂东"=>"101250511","常德"=>"101250601","安乡"=>"101250602","桃源"=>"101250603","汉寿

"=>"101250604","澧县"=>"101250605","临澧"=>"101250606","石门"=>"101250607","益阳"=>"101250700","赫山区"=>"101250701","南县

"=>"101250702","桃江"=>"101250703","安化"=>"101250704","沅江"=>"101250705","娄底"=>"101250801","双峰"=>"101250802","冷水江

"=>"101250803","冷水滩"=>"101250804","新化"=>"101250805","涟源"=>"101250806","邵阳"=>"101250901","隆回"=>"101250902","洞口

"=>"101250903","新邵"=>"101250904","邵东"=>"101250905","绥宁"=>"101250906","新宁"=>"101250907","武冈"=>"101250908","城步

"=>"101250909","邵阳县"=>"101250910","岳阳"=>"101251001","华容"=>"101251002","湘阴"=>"101251003","汨罗"=>"101251004","平江

"=>"101251005","临湘"=>"101251006","张家界"=>"101251101","桑植"=>"101251102","慈利"=>"101251103","怀化"=>"101251201","鹤城区

"=>"101251202","沅陵"=>"101251203","辰溪"=>"101251204","靖州"=>"101251205","会同"=>"101251206","通道"=>"101251207","麻阳

"=>"101251208","新晃"=>"101251209","芷江"=>"101251210","溆浦"=>"101251211","黔阳"=>"101251301","洪江"=>"101251302","永州

"=>"101251401","祁阳"=>"101251402","东安"=>"101251403","双牌"=>"101251404","道县"=>"101251405","宁远"=>"101251406","江永

"=>"101251407","蓝山"=>"101251408","新田"=>"101251409","江华"=>"101251410","吉首"=>"101251501","保靖"=>"101251502","永顺

"=>"101251503","古丈"=>"101251504","凤凰"=>"101251505","泸溪"=>"101251506","龙山"=>"101251507","花垣"=>"101251508",

"贵阳"=>"101260101","白云"=>"101260102","花溪"=>"101260103","乌当"=>"101260104","息烽"=>"101260105","开阳"=>"101260106","修文

"=>"101260107","清镇"=>"101260108","遵义"=>"101260201","遵义县"=>"101260202","仁怀"=>"101260203","绥阳"=>"101260204","湄潭

# --------------- SD²固件操作指南------

"=>"101260205","凤冈"=>"101260206","桐梓"=>"101260207","赤水"=>"101260208","习水"=>"101260209","道真"=>"101260210","正安

"=>"101260211","务川"=>"101260212","余庆"=>"101260213","汇川"=>"101260214","安顺"=>"101260301","普定"=>"101260302","镇宁

"=>"101260303","平坝"=>"101260304","紫云"=>"101260305","关岭"=>"101260306","都匀"=>"101260401","贵定"=>"101260402","瓮安

"=>"101260403","长顺"=>"101260404","福泉"=>"101260405","惠水"=>"101260406","龙里"=>"101260407","罗甸"=>"101260408","平塘

"=>"101260409","独山"=>"101260410","三都"=>"101260411","荔波"=>"101260412","凯里"=>"101260501","岑巩"=>"101260502","施秉

"=>"101260503","镇远"=>"101260504","黄平"=>"101260505","黄平旧洲"=>"101260506","麻江"=>"101260507","丹寨"=>"101260508","三穗

"=>"101260509","台江"=>"101260510","剑河"=>"101260511","雷山"=>"101260512","黎平"=>"101260513","天柱"=>"101260514","锦屏

"=>"101260515","榕江"=>"101260516","从江"=>"101260517","炉山"=>"101260518","铜仁"=>"101260601","江口"=>"101260602","玉屏

"=>"101260603","万山"=>"101260604","思南"=>"101260605","塘头"=>"101260606","印江"=>"101260607","石阡"=>"101260608","沿河

"=>"101260609","德江"=>"101260610","松桃"=>"101260611","毕节"=>"101260701","赫章"=>"101260702","金沙"=>"101260703","威宁

"=>"101260704","大方"=>"101260705","纳雍"=>"101260706","织金"=>"101260707","六盘水"=>"101260801","六枝"=>"101260802","水城

"=>"101260803","盘县"=>"101260804","黔西"=>"101260901","晴隆"=>"101260902","兴仁"=>"101260903","贞丰"=>"101260904","望谟

"=>"101260905","兴义"=>"101260906","安龙"=>"101260907","册亨"=>"101260908","普安"=>"101260909",

"成都"=>"101270101","龙泉驿"=>"101270102","新都"=>"101270103","温江"=>"101270104","金堂"=>"101270105","双流"=>"101270106","郫县

"=>"101270107","大邑"=>"101270108","蒲江"=>"101270109","新津"=>"101270110","都江堰"=>"101270111","彭州"=>"101270112","邛崃

"=>"101270113","崇州"=>"101270114","崇庆"=>"101270115","彭县"=>"101270116","攀枝花"=>"101270201","仁和"=>"101270202","米易

"=>"101270203","盐边"=>"101270204","自贡"=>"101270301","富顺"=>"101270302","荣县"=>"101270303","绵阳"=>"101270401","三台

"=>"101270402","盐亭"=>"101270403","安县"=>"101270404","梓潼"=>"101270405","北川"=>"101270406","平武"=>"101270407","江油

"=>"101270408","南充"=>"101270501","南部"=>"101270502","营山"=>"101270503","蓬安"=>"101270504","仪陇"=>"101270505","西充

"=>"101270506","阆中"=>"101270507","达州"=>"101270601","宣汉"=>"101270602","开江"=>"101270603","大竹"=>"101270604","渠县

"=>"101270605","万源"=>"101270606","达川"=>"101270607","遂宁"=>"101270701","蓬溪"=>"101270702","射洪"=>"101270703","广安

"=>"101270801","岳池"=>"101270802","武胜"=>"101270803","邻水"=>"101270804","华蓥山"=>"101270805","巴中"=>"101270901","通江

"=>"101270902","南江"=>"101270903","平昌"=>"101270904","泸州"=>"101271001","泸县"=>"101271003","合江"=>"101271004","叙永

"=>"101271005","古蔺"=>"101271006","纳溪"=>"101271007","宜宾"=>"101271101","宜宾农试站"=>"101271102","宜宾县"=>"101271103","南

溪"=>"101271104","江安"=>"101271105","长宁"=>"101271106","高县"=>"101271107","珙县"=>"101271108","筠连"=>"101271109","兴文

"=>"101271110","屏山"=>"101271111","内江"=>"101271201","东兴"=>"101271202","威远"=>"101271203","资中"=>"101271204","隆昌

"=>"101271205","资阳"=>"101271301","安岳"=>"101271302","乐至"=>"101271303","简阳"=>"101271304","乐山"=>"101271401","犍为

"=>"101271402","井研"=>"101271403","夹江"=>"101271404","沐川"=>"101271405","峨边"=>"101271406","马边"=>"101271407","峨眉

"=>"101271408","峨眉山"=>"101271409","眉山"=>"101271501","仁寿"=>"101271502","彭山"=>"101271503","洪雅"=>"101271504","丹棱

"=>"101271505","青神"=>"101271506","凉山"=>"101271601","木里"=>"101271603","盐源"=>"101271604","德昌"=>"101271605","会理

"=>"101271606","会东"=>"101271607","宁南"=>"101271608","普格"=>"101271609","西昌"=>"101271610","金阳"=>"101271611","昭觉

"=>"101271612","喜德"=>"101271613","冕宁"=>"101271614","越西"=>"101271615","甘洛"=>"101271616","雷波"=>"101271617","美姑

"=>"101271618","布拖"=>"101271619","雅安"=>"101271701","名山"=>"101271702","荣经"=>"101271703","汉源"=>"101271704","石棉

"=>"101271705","天全"=>"101271706","芦山"=>"101271707","宝兴"=>"101271708","甘孜"=>"101271801","康定"=>"101271802","泸定

"=>"101271803","丹巴"=>"101271804","九龙"=>"101271805","雅江"=>"101271806","道孚"=>"101271807","炉霍"=>"101271808","新龙

"=>"101271809","德格"=>"101271810","白玉"=>"101271811","石渠"=>"101271812","色达"=>"101271813","理塘"=>"101271814","巴塘

"=>"101271815","乡城"=>"101271816","稻城"=>"101271817","得荣"=>"101271818","阿坝"=>"101271901","汶川"=>"101271902","理县

"=>"101271903","茂县"=>"101271904","松潘"=>"101271905","九寨沟"=>"101271906","金川"=>"101271907","小金"=>"101271908","黑水

"=>"101271909","马尔康"=>"101271910","壤塘"=>"101271911","若尔盖"=>"101271912","红原"=>"101271913","南坪"=>"101271914","德阳

"=>"101272001","中江"=>"101272002","广汉"=>"101272003","什邡"=>"101272004","绵竹"=>"101272005","罗江"=>"101272006","广元

# --------------- SD²固件操作指南------

"=>"101272101","旺苍"=>"101272102","青川"=>"101272103","剑阁"=>"101272104","苍溪"=>"101272105",

"广州"=>"101280101","番禺"=>"101280102","从化"=>"101280103","增城"=>"101280104","花都"=>"101280105","天河"=>"101280106","韶关

"=>"101280201","乳源"=>"101280202","始兴"=>"101280203","翁源"=>"101280204","乐昌"=>"101280205","仁化"=>"101280206","南雄

"=>"101280207","新丰"=>"101280208","曲江"=>"101280209","惠州"=>"101280301","博罗"=>"101280302","惠阳"=>"101280303","惠东

"=>"101280304","龙门"=>"101280305","梅州"=>"101280401","兴宁"=>"101280402","蕉岭"=>"101280403","大埔"=>"101280404","丰顺

"=>"101280406","平远"=>"101280407","五华"=>"101280408","梅县"=>"101280409","汕头"=>"101280501","潮阳"=>"101280502","澄海

"=>"101280503","南澳"=>"101280504","云澳"=>"101280505","南澎岛"=>"101280506","深圳"=>"101280601","珠海"=>"101280701","斗门

"=>"101280702","黄茅洲"=>"101280703","佛山"=>"101280800","顺德"=>"101280801","三水"=>"101280802","南海"=>"101280803","肇庆

"=>"101280901","广宁"=>"101280902","四会"=>"101280903","德庆"=>"101280905","怀集"=>"101280906","封开"=>"101280907","高要

"=>"101280908","湛江"=>"101281001","吴川"=>"101281002","雷州"=>"101281003","徐闻"=>"101281004","廉江"=>"101281005","硇洲

"=>"101281006","遂溪"=>"101281007","江门"=>"101281101","开平"=>"101281103","新会"=>"101281104","恩平"=>"101281105","台山

"=>"101281106","上川岛"=>"101281107,"鹤山"=>"101281108","河源"=>"101281201","紫金"=>"101281202","连平"=>"101281203","和平

"=>"101281204","龙川"=>"101281205","清远"=>"101281301","连南"=>"101281302","连州"=>"101281303","连山"=>"101281304","阳山

"=>"101281305","佛冈"=>"101281306","英德"=>"101281307","云浮"=>"101281401","罗定"=>"101281402","新兴"=>"101281403","郁南

"=>"101281404","潮州"=>"101281501","饶平"=>"101281502","东莞"=>"101281601","中山"=>"101281701","阳江"=>"101281801","阳春

"=>"101281802","揭阳"=>"101281901","揭西"=>"101281902","普宁"=>"101281903","惠来"=>"101281904","茂名"=>"101282001","高州

"=>"101282002","化州"=>"101282003","电白"=>"101282004","信宜"=>"101282005","汕尾"=>"101282101","海丰"=>"101282102","陆丰

"=>"101282103","遮浪"=>"101282104","东沙岛"=>"101282105",

"昆明"=>"101290101","昆明农试站"=>"101290102","东川"=>"101290103","寻甸"=>"101290104","晋宁"=>"101290105","宜良"=>"101290106","

石林"=>"101290107","呈贡"=>"101290108","富民"=>"101290109","嵩明"=>"101290110","禄劝"=>"101290111","安宁"=>"101290112","太华山

"=>"101290113","河口"=>"101290114","大理"=>"101290201","云龙"=>"101290202","漾鼻"=>"101290203","永平"=>"101290204","宾川

"=>"101290205","弥渡"=>"101290206","祥云"=>"101290207","魏山"=>"101290208","剑川"=>"101290209","洱源"=>"101290210","鹤庆

"=>"101290211","南涧"=>"101290212","红河"=>"101290301","石屏"=>"101290302","建水"=>"101290303","弥勒"=>"101290304","元阳

"=>"101290305","绿春"=>"101290306","开远"=>"101290307","个旧"=>"101290308","蒙自"=>"101290309","屏边"=>"101290310","泸西

"=>"101290311","金平"=>"101290312","曲靖"=>"101290401","沾益"=>"101290402","陆良"=>"101290403","富源"=>"101290404","马龙

"=>"101290405","师宗"=>"101290406","罗平"=>"101290407","会泽"=>"101290408","宣威"=>"101290409","保山"=>"101290501","富宁

"=>"101290502","龙陵"=>"101290503","施甸"=>"101290504","昌宁"=>"101290505","腾冲"=>"101290506","文山"=>"101290601","西畴

"=>"101290602","马关"=>"101290603","麻栗坡"=>"101290604","砚山"=>"101290605","邱北"=>"101290606","广南"=>"101290607","玉溪

"=>"101290701","澄江"=>"101290702","江川"=>"101290703","通海"=>"101290704","华宁"=>"101290705","新平"=>"101290706","易门

"=>"101290707","峨山"=>"101290708","元江"=>"101290709","楚雄"=>"101290801","大姚"=>"101290802","元谋"=>"101290803","姚安

"=>"101290804","牟定"=>"101290805","南华"=>"101290806","武定"=>"101290807","禄丰"=>"101290808","双柏"=>"101290809","永仁

"=>"101290810","普洱"=>"101290901","景谷"=>"101290902","景东"=>"101290903","澜沧"=>"101290904","普洱"=>"101290905","墨江

"=>"101290906","江城"=>"101290907","孟连"=>"101290908","西盟"=>"101290909","镇源"=>"101290910","镇沅"=>"101290911","宁洱

"=>"101290912","昭通"=>"101291001","鲁甸"=>"101291002","彝良"=>"101291003","镇雄"=>"101291004","威信"=>"101291005","巧家

"=>"101291006","绥江"=>"101291007","永善"=>"101291008","盐津"=>"101291009","大关"=>"101291010","临沧"=>"101291101","沧源

"=>"101291102","耿马"=>"101291103","双江"=>"101291104","凤庆"=>"101291105","永德"=>"101291106","云县"=>"101291107","镇康

"=>"101291108","怒江"=>"101291201","福贡"=>"101291203","兰坪"=>"101291204","泸水"=>"101291205","六库"=>"101291206","贡山

"=>"101291207","香格里拉"=>"101291301","德钦"=>"101291302","维西"=>"101291303","中甸"=>"101291304","丽江"=>"101291401","永胜

"=>"101291402","华坪"=>"101291403","宁蒗"=>"101291404","德宏"=>"101291501","潞江坝"=>"101291502","陇川"=>"101291503","盈江

# --------------- SD²固件操作指南------

"=>"101291504","畹町镇"=>"101291505","瑞丽"=>"101291506","梁河"=>"101291507","潞西"=>"101291508","景洪"=>"101291601","大勐龙

"=>"101291602","勐海"=>"101291603","景洪电站"=>"101291604","勐腊"=>"101291605",

"南宁"=>"101300101","南宁城区"=>"101300102","邕宁"=>"101300103","横县"=>"101300104","隆安"=>"101300105","马山"=>"101300106","上

林"=>"101300107","武鸣"=>"101300108","宾阳"=>"101300109","硕龙"=>"101300110","崇左"=>"101300201","天等"=>"101300202","龙州

"=>"101300203","凭祥"=>"101300204","大新"=>"101300205","扶绥"=>"101300206","宁明"=>"101300207","海渊"=>"101300208","柳州

"=>"101300301","柳城"=>"101300302","沙塘"=>"101300303","鹿寨"=>"101300304","柳江"=>"101300305","融安"=>"101300306","融水

"=>"101300307","三江"=>"101300308","来宾"=>"101300401","忻城"=>"101300402","金秀"=>"101300403","象州"=>"101300404","武宣

"=>"101300405","桂林"=>"101300501","桂林农试站"=>"101300502","龙胜"=>"101300503","永福"=>"101300504","临桂"=>"101300505","兴安

"=>"101300506","灵川"=>"101300507","全州"=>"101300508","灌阳"=>"101300509","阳朔"=>"101300510","恭城"=>"101300511","平乐

"=>"101300512","荔浦"=>"101300513","资源"=>"101300514","梧州"=>"101300601","藤县"=>"101300602","太平"=>"101300603","苍梧

"=>"101300604","蒙山"=>"101300605","岑溪"=>"101300606","贺州"=>"101300701","昭平"=>"101300702","富川"=>"101300703","钟山

"=>"101300704","信都"=>"101300705","贵港"=>"101300801","桂平"=>"101300802","平南"=>"101300803","玉林"=>"101300901","博白

"=>"101300902","北流"=>"101300903","容县"=>"101300904","陆川"=>"101300905","百色"=>"101301001","那坡"=>"101301002","田阳

"=>"101301003","德保"=>"101301004","靖西"=>"101301005","田东"=>"101301006","平果"=>"101301007","隆林"=>"101301008","西林

"=>"101301009","乐业"=>"101301010","凌云"=>"101301011","田林"=>"101301012","钦州"=>"101301101","浦北"=>"101301102","灵山

"=>"101301103","河池"=>"101301201","天峨"=>"101301202","东兰"=>"101301203","巴马"=>"101301204","环江"=>"101301205","罗城

"=>"101301206","宜州"=>"101301207","凤山"=>"101301208","南丹"=>"101301209","都安"=>"101301210","北海"=>"101301301","合浦

"=>"101301302","涠洲岛"=>"101301303","防城港"=>"101301401","上思"=>"101301402","东兴"=>"101301403","板栏"=>"101301404","防城

"=>"101301405",

"海口"=>"101310101","琼山"=>"101310102","三亚"=>"101310201","东方"=>"101310202","临高"=>"101310203","澄迈"=>"101310204","儋州

"=>"101310205","昌江"=>"101310206","白沙"=>"101310207","琼中"=>"101310208","定安"=>"101310209","屯昌"=>"101310210","琼海

"=>"101310211","文昌"=>"101310212","清兰"=>"101310213","保亭"=>"101310214","万宁"=>"101310215","陵水"=>"101310216","西沙

"=>"101310217","珊瑚岛"=>"101310218","永署礁"=>"101310219","南沙岛"=>"101310220","乐东"=>"101310221","五指山"=>"101310222","通

什"=>"101310223",

"香港"=>"101320101","九龙"=>"101320102","新界"=>"101320103","中环"=>"101320104","铜锣湾"=>"101320105",

"澳门"=>"101330101",

"台北县"=>"101340101","台北市"=>"101340102","高雄"=>"101340201","东港"=>"101340202","大武"=>"101340203","恒春"=>"101340204","兰

屿"=>"101340205","台南"=>"101340301","台中"=>"101340401","桃园"=>"101340501","新竹县"=>"101340601","新竹市"=>"101340602","公馆

"=>"101340603","宜兰"=>"101340701","马公"=>"101340801","东吉屿"=>"101340802","嘉义"=>"101340901","阿里山"=>"101340902","玉山

"=>"101340903","新港"=>"101340904"

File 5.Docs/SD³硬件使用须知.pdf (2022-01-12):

# --------------- SD³硬件使用须知------

## 焊接图

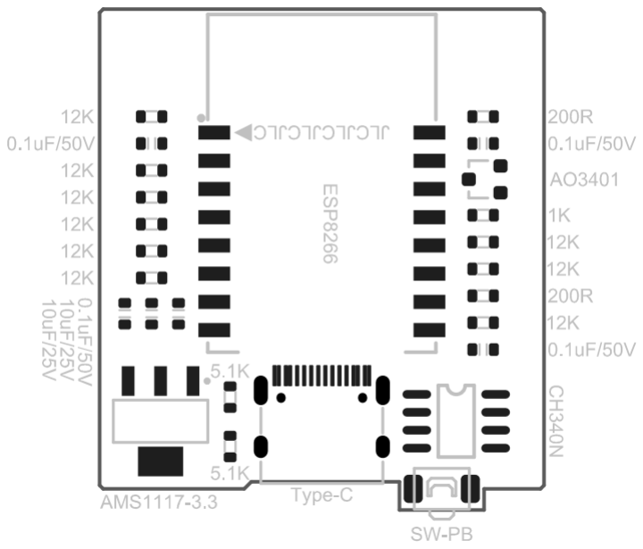
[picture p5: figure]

# --------------- SD³硬件使用须知------

## 下载程序

1. 确保已经正确安装 CH340 驱动程序
2. 点击软件下载按钮
3. 软件进入下载后按一下复位按钮，位于 USB 线左侧，如图

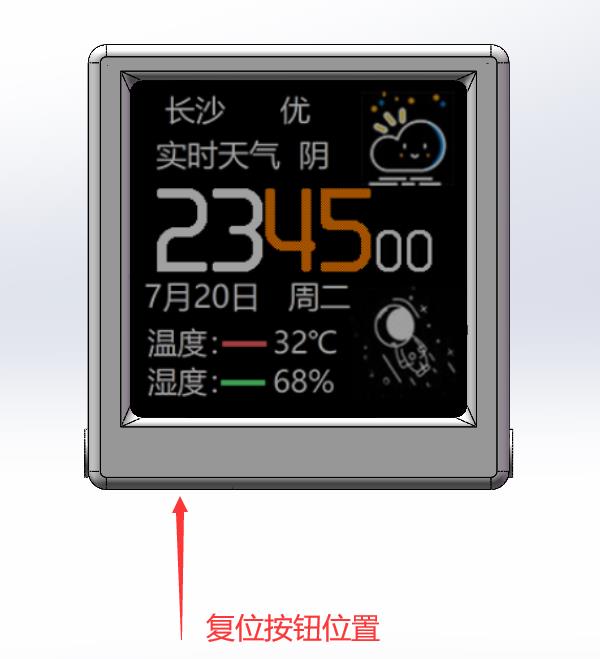
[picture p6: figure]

4. 下载完成后再次按一下复位按钮

下载技巧：
点击下载按钮，命令行显示下划线“____”时候按下复位按钮；显示完 4 个点“....”约 0.5 秒 后松开即可进入下载。

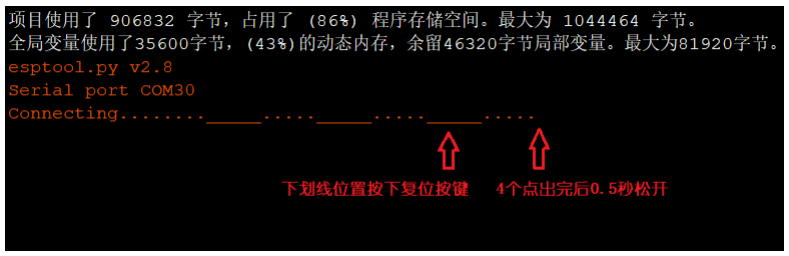
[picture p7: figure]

## By Misaka

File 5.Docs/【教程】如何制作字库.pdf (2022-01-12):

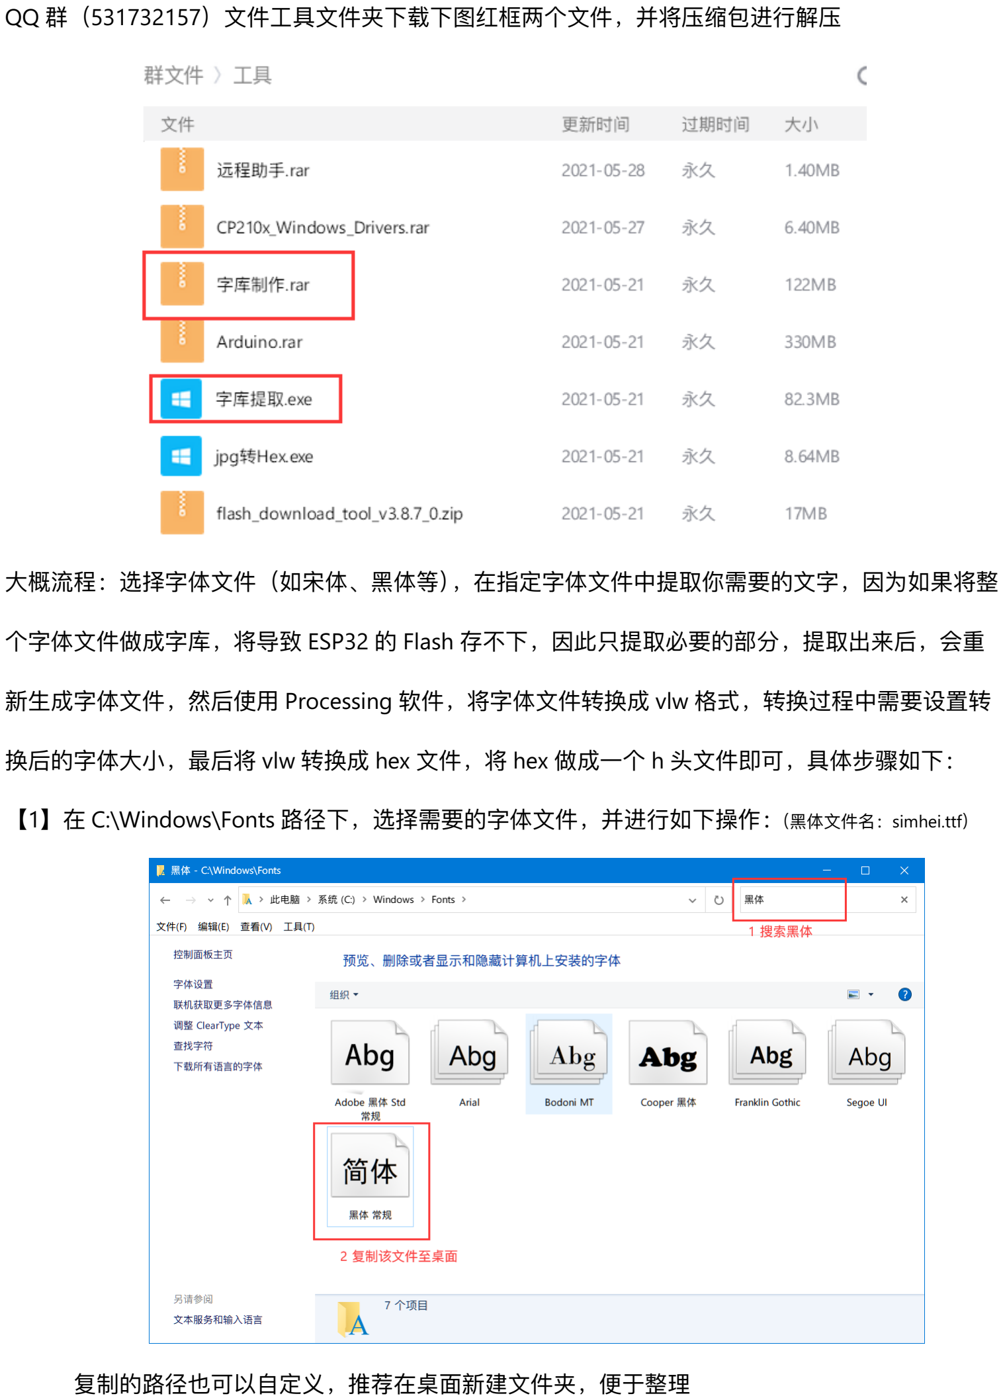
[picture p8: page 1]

QQ 群（531732157）文件工具文件夹下载下图红框两个文件，并将压缩包进行解压

大概流程：选择字体文件（如宋体、黑体等），在指定字体文件中提取你需要的文字，因为如果将整

个字体文件做成字库，将导致 ESP32 的 Flash 存不下，因此只提取必要的部分，提取出来后，会重

新生成字体文件，然后使用 Processing 软件，将字体文件转换成 vlw 格式，转换过程中需要设置转

换后的字体大小，最后将 vlw 转换成 hex 文件，将 hex 做成一个 h 头文件即可，具体步骤如下：

【1】在 C:\Windows\Fonts 路径下，选择需要的字体文件，并进行如下操作：（黑体文件名：simhei.ttf）

复制的路径也可以自定义，推荐在桌面新建文件夹，便于整理

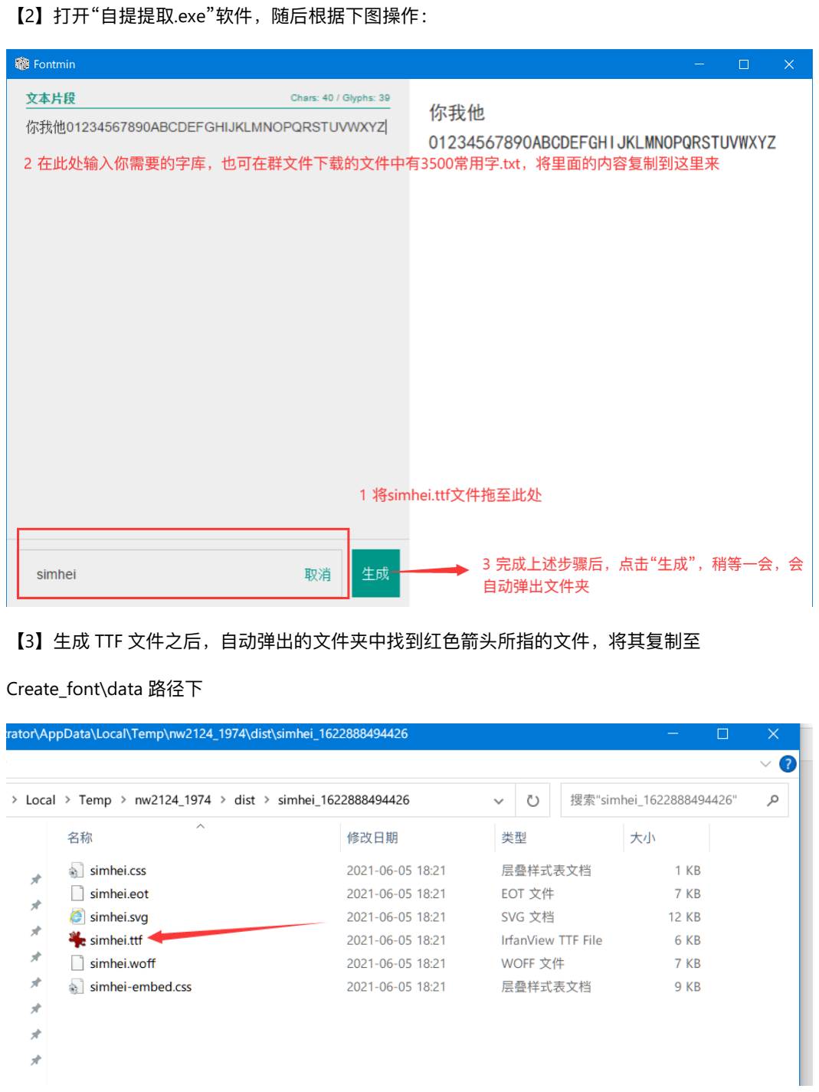
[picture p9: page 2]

【2】打开“自提提取.exe”软件，随后根据下图操作：

【3】生成 TTF 文件之后，自动弹出的文件夹中找到红色箭头所指的文件，将其复制至

Create_font\data 路径下

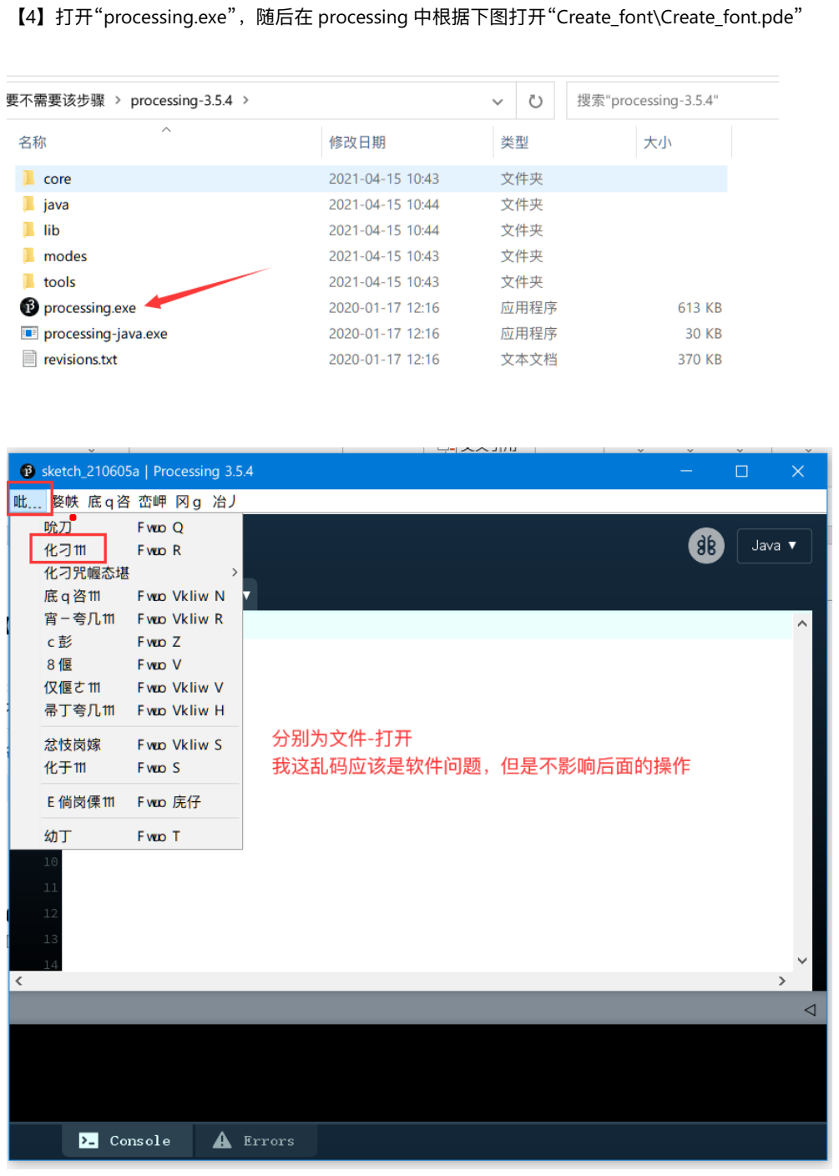
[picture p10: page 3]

【4】打开“processing.exe”，随后在 processing 中根据下图打开“Create_font\Create_font.pde”

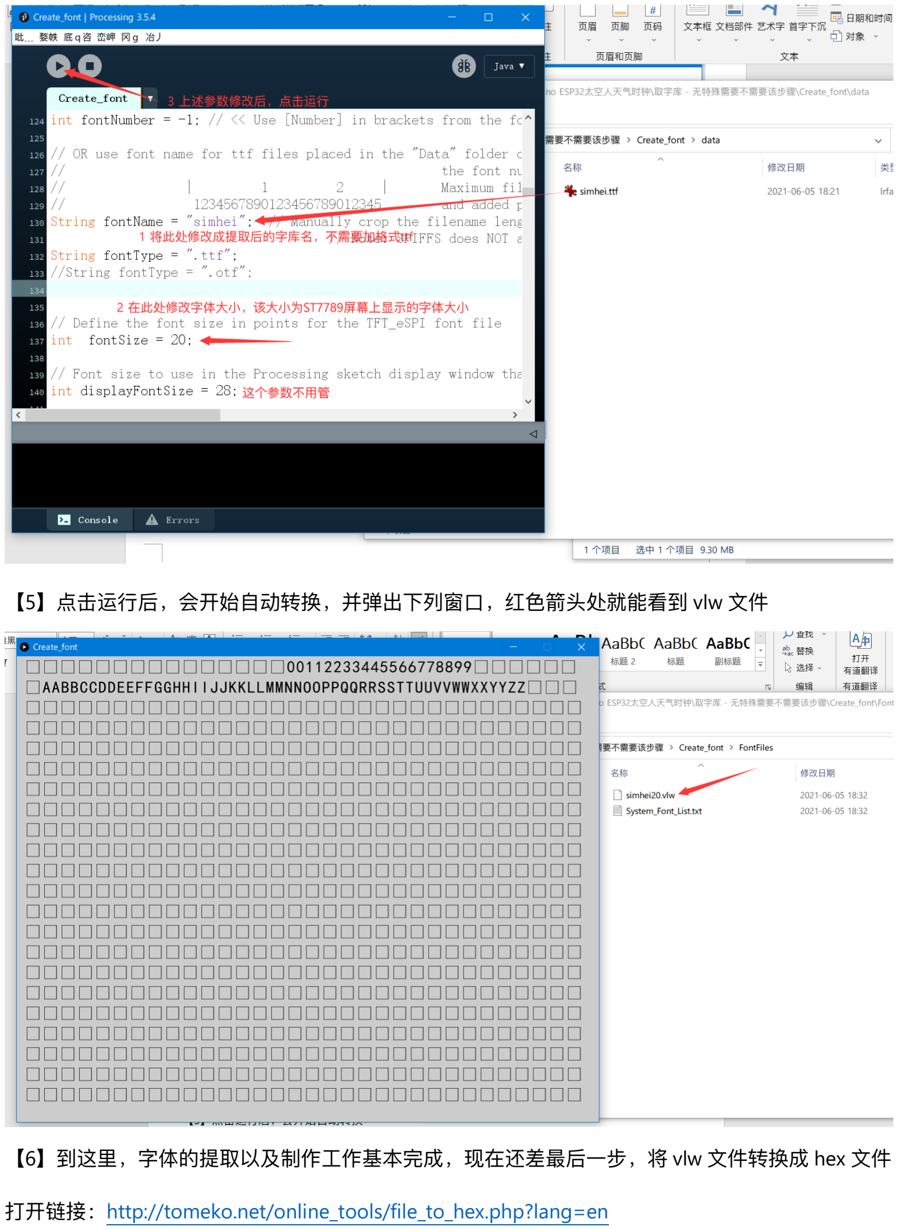
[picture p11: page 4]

【5】点击运行后，会开始自动转换，并弹出下列窗口，红色箭头处就能看到 vlw 文件

【6】到这里，字体的提取以及制作工作基本完成，现在还差最后一步，将 vlw 文件转换成 hex 文件

打开链接：http://tomeko.net/online_tools/file_to_hex.php?lang=en

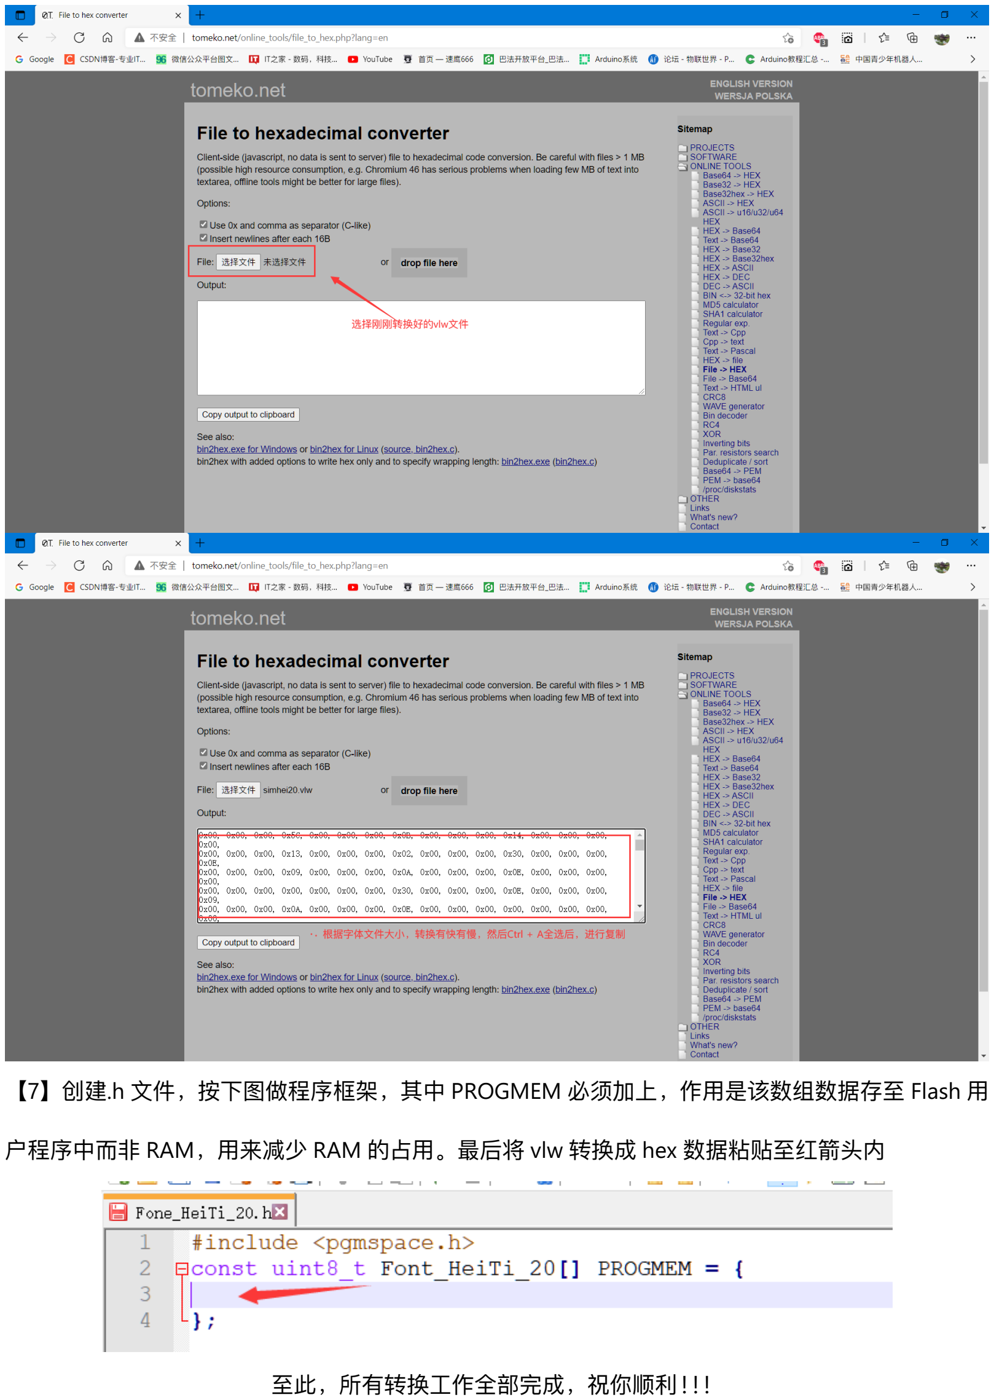
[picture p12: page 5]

【7】创建.h 文件，按下图做程序框架，其中 PROGMEM 必须加上，作用是该数组数据存至 Flash 用

户程序中而非 RAM，用来减少 RAM 的占用。最后将 vlw 转换成 hex 数据粘贴至红箭头内

至此，所有转换工作全部完成，祝你顺利！！！

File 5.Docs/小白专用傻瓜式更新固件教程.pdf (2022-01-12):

# ---------------- 固件升级方式--------

### 一、下载所需用到的软件

1、 CH340 驱动程序
2、 flash_download_tools
文件可在群文件找到，如图

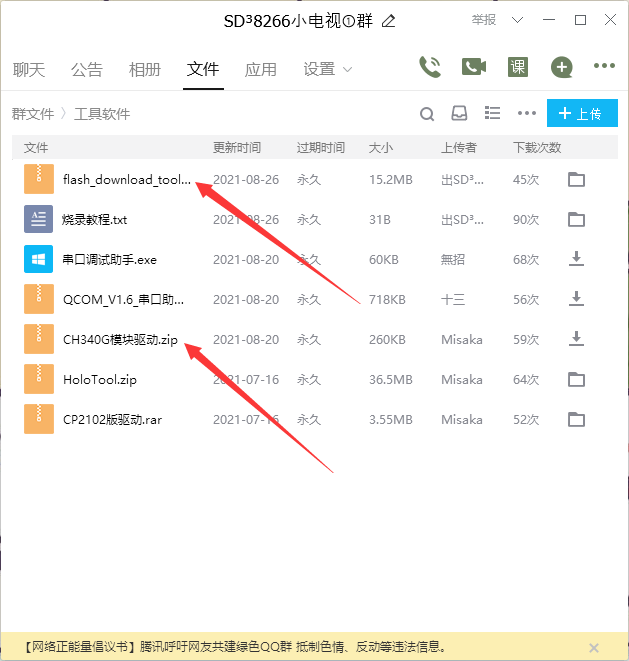
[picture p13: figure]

### 二、安装 CH340 驱动

1、 将设备插到电脑；
2、 解压压缩包，双击“CH341SER.EXE”； 3、 等待安装成功后退出。

### 三、程序下载

1、 先准备好需要下载的.bin 文件

注：.bin 文件在程序文件夹内找后缀为 .ino.nodemcu.bin 的文件，如图

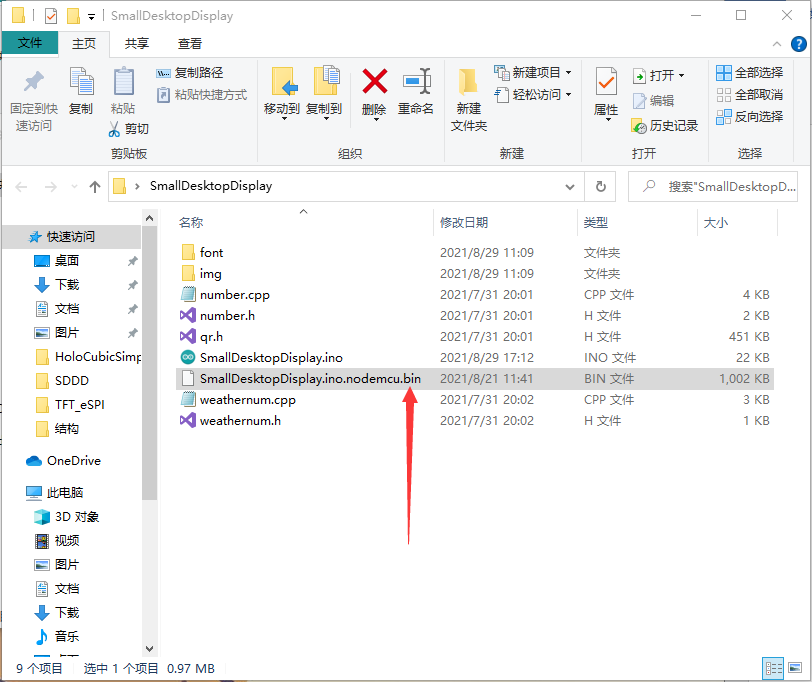
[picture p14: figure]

# ---------------- 固件升级方式--------

2、打开 flash_download_tools 工具，选择 ESP8266 DownloadTool；

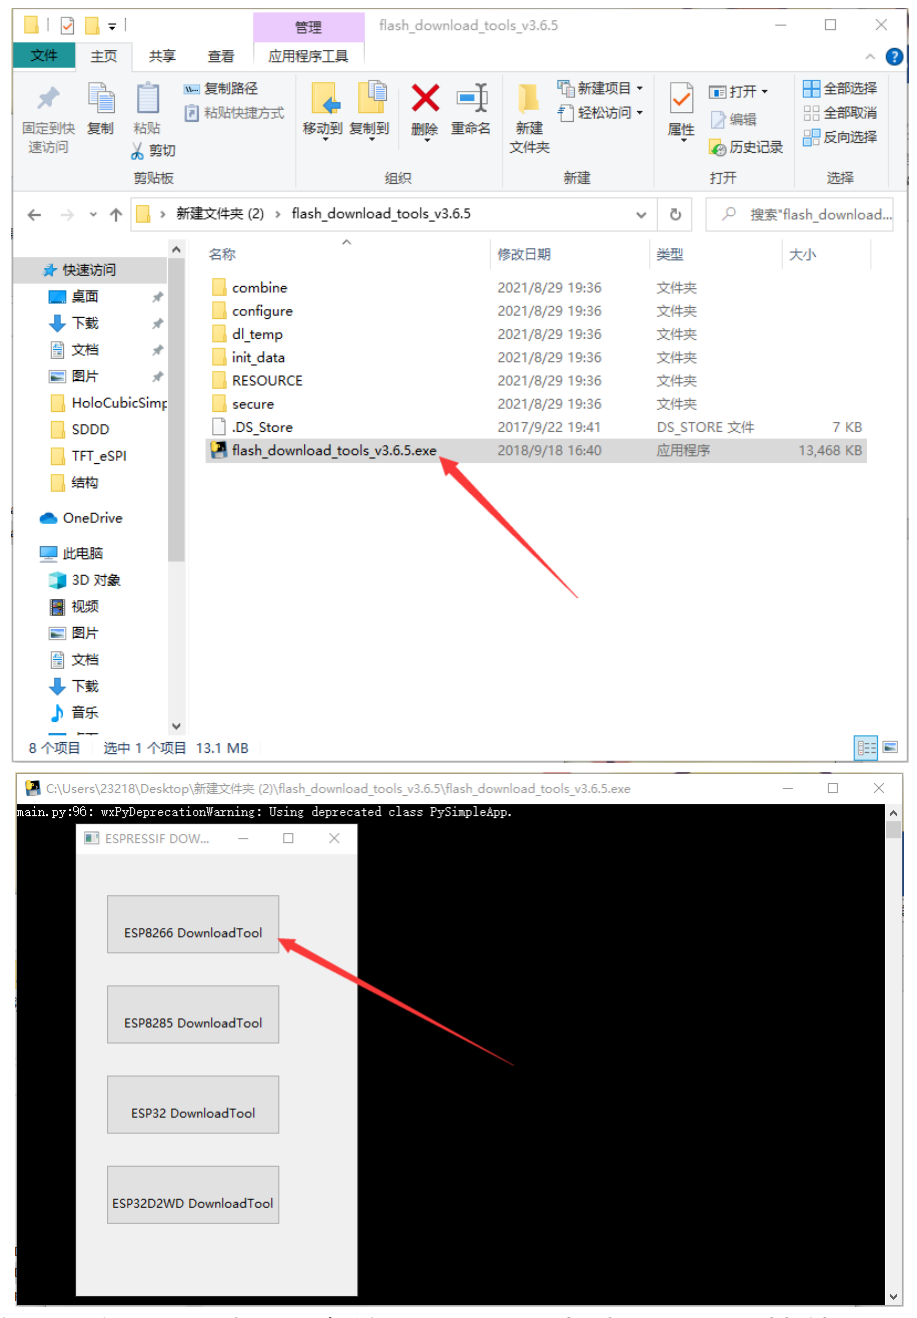
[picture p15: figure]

2、 选择刚刚的.bin 文件，选择正确的 COM口，点击 START(其他设置不相同处请更改)；

注：SD³在点击 START 后需要按下数据线左侧的复位按钮大约 0.5S，松开后进度条才会走。

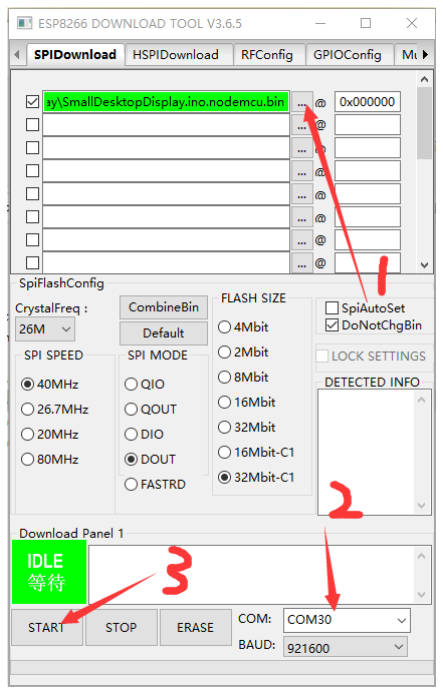
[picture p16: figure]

# ---------------- 固件升级方式--------

4、等待进度条走完，将设备拔电重启(进度条完成后最好等几秒)；

完～

感谢 WH

### By Misaka

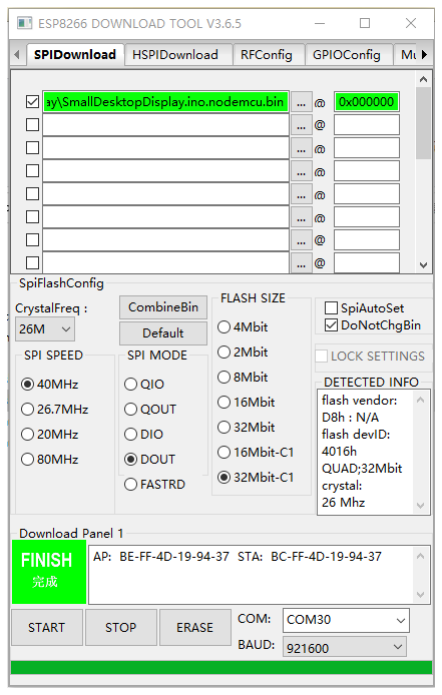
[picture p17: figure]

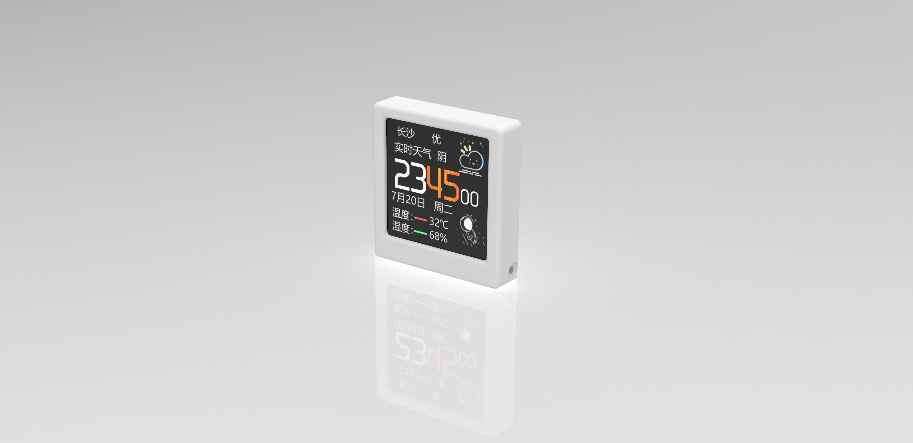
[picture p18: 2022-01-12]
1.Hardware/SD3-电脑主机显示/渲染图/SD³渲染图.png

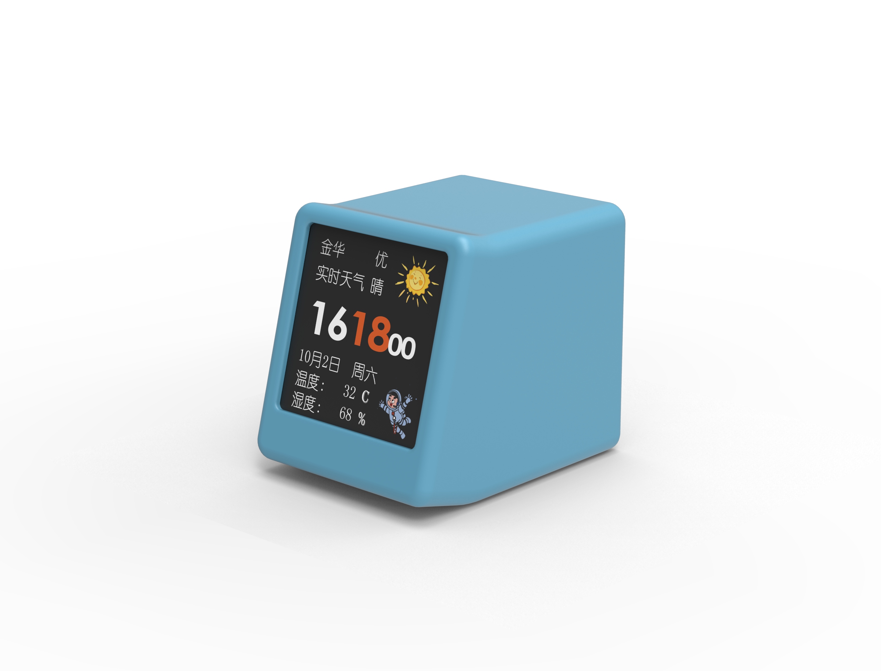
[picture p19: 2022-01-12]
1.Hardware/SD2-推荐桌面摆件/渲染图/SD2.jpg

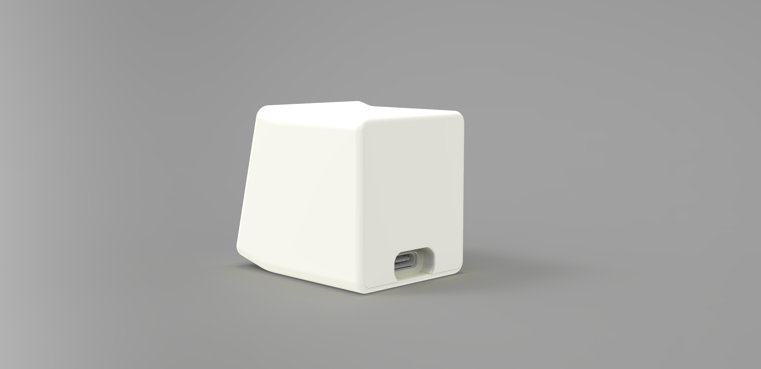
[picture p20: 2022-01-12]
1.Hardware/SD2-推荐桌面摆件/渲染图/渲染图4.png

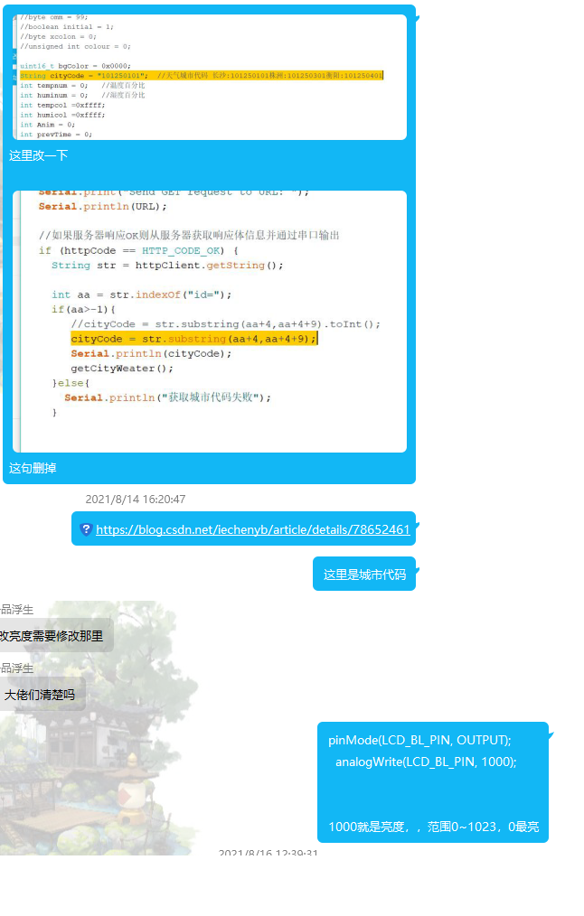
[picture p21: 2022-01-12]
1.Hardware/手动改地址和亮度代码位置.bmp

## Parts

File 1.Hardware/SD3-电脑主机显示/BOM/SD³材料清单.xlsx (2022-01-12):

Designator | Comment | Footprint | Quantity
C1, C2 | 10uF/25V | C_0603 | 2
C3, C4, C5, C6 | 0.1uF/50V | C_0603 | 4
LCD1 | ST7789-240x240-1.54TFT | LCD-240X240-12P | 1
Q1 | AO3401 | SOT-23-y | 1
R1 | 1K | R_0603 | 1
R2, R3 | 5.1K | R_0603 | 2
R4, R5, R6, R7, R9, R11, R12, R13, R14 | 12K | R_0603 | 9
R8, R10 | 200R | R_0603 | 2
S1 | 小龟按键 | YD-3410 | 1
U1 | AMS1117-3.3 | SOT223 | 1
U2 | ESP8266 | ESP12F | 1
U3 | CH340N | SO-8 | 1
USB1 | Type-C-16P | Type-C-16P | 1
附件
外壳 | 外壳V1.1 |  | 1
内壳 | 内壳V1.1 |  | 1
PCB板 | SD³V1.2以上版本 |  | 1
螺丝 | M2*3mm |  | 2

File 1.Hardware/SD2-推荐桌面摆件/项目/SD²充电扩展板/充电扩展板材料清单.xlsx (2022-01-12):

Designator | Comment | Footprint | Quantity
C1, C6 | 10uF | C_0603 | 2
C2, C3, C7 | 0.1uF | C_0603 | 3
C4 | 10nF | C_0603 | 1
J1 | Battery | C_1812 | 1
L1 | 2.2uH | CD32 | 1
LED1 | RED | 0603/1608 LEDR | 1
LED2 | BLUE | 0603/1608 LEDB | 1
P1 | FPC座0.5mm8P | FFC_0.5_8 | 1
R1 | 12K | R_0603 | 1
R2 | 2K | R_0603 | 1
R3, R5, R6 | 1K | R_0603 | 3
R4 | 3K | R_0603 | 1
R7 | 453K | R_0603 | 1
R8 | 100K | R_0603 | 1
U1 | TP4057 | SOT23-6 | 1
U2 | FP6381A | SOT23-5 | 1
附件
PCB板 | SD²充电扩展板 |  | 1
软排线 | FPC 0.5mm8P | 6cm，同向 | 1

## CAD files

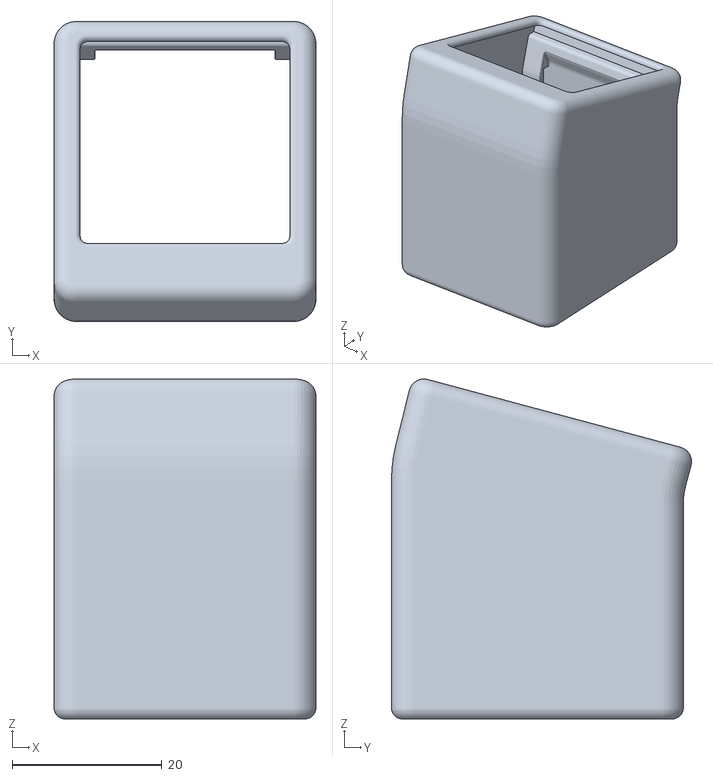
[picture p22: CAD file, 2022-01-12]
4.3D Model/SD2/1.1/主体1.1.STL
35.0 x 40.1 x 45.4

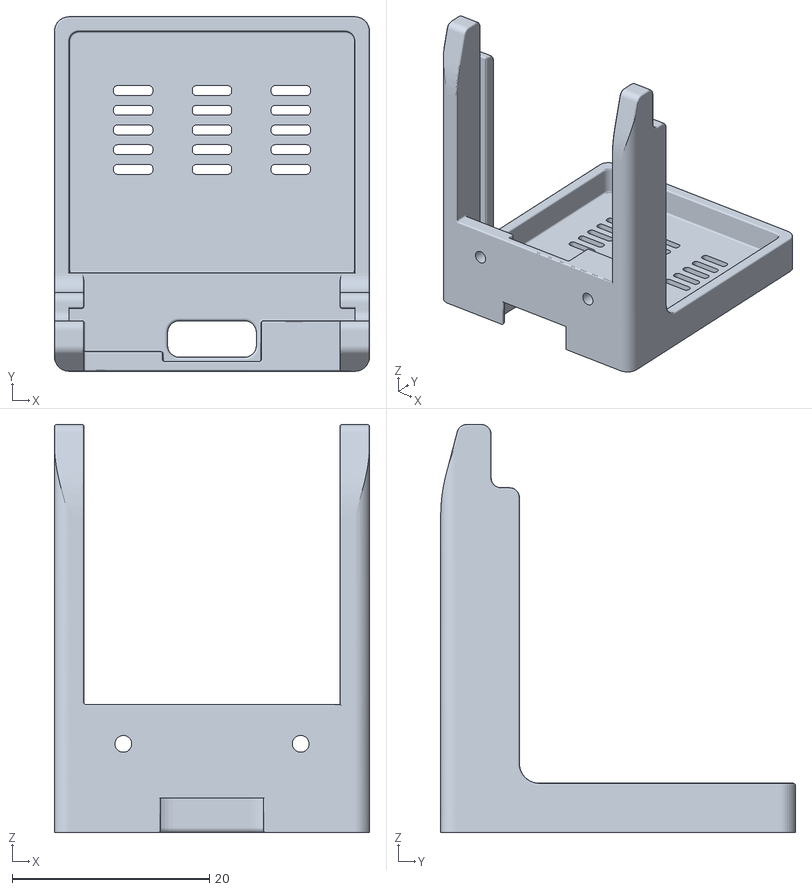
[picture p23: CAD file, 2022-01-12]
4.3D Model/SD2/1.2/后壳1.2.STL
32.0 x 36.0 x 41.4

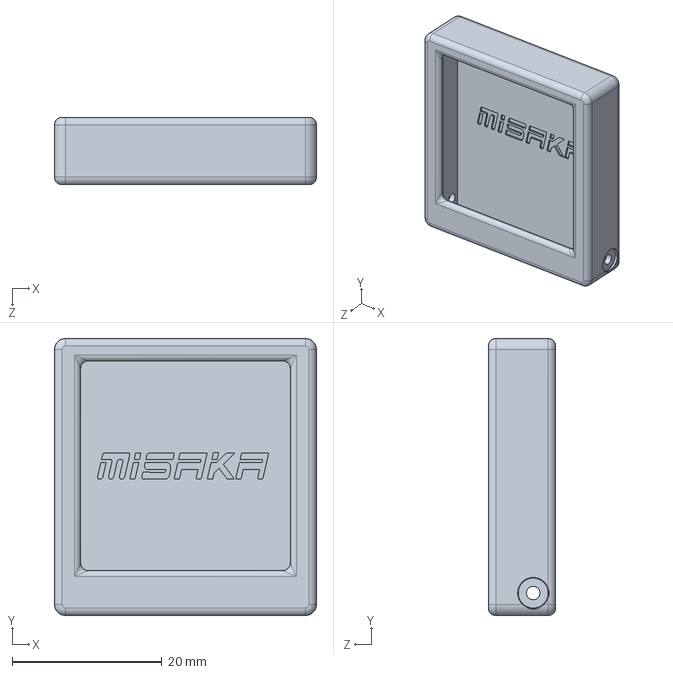
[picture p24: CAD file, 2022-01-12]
4.3D Model/SD3/SD³外壳1.1版本step文件/外壳.STEP
35.0 x 37.0 x 9.00 mm

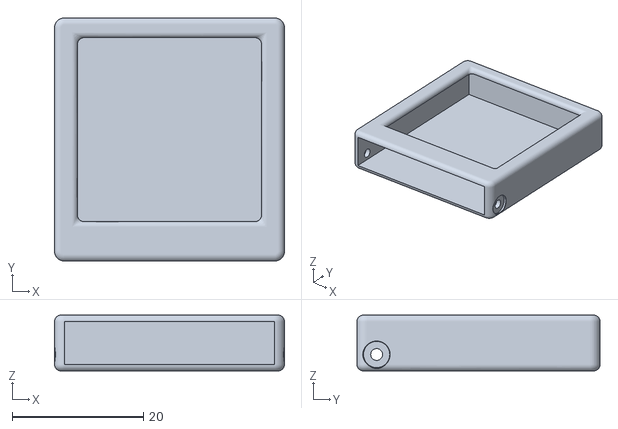
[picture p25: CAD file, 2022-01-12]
4.3D Model/SD3/sw/外壳.STL
35.0 x 37.0 x 8.50

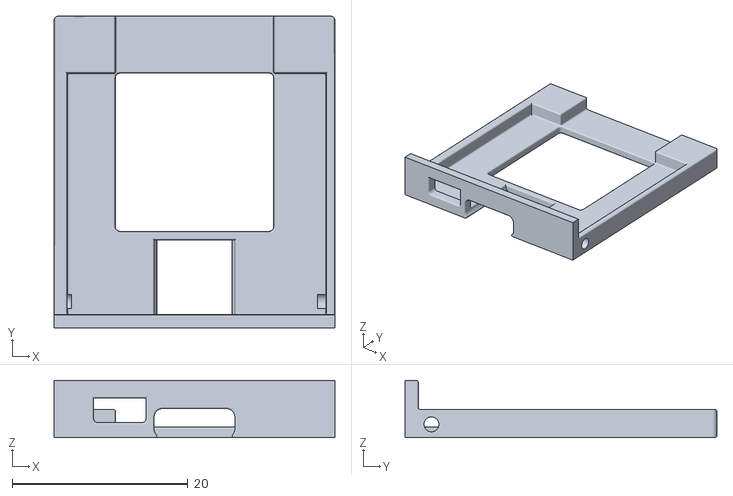
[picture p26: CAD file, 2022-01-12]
4.3D Model/SD3/外壳3D文件（推荐）/内壳V1.1.STL
32.0 x 35.5 x 6.50

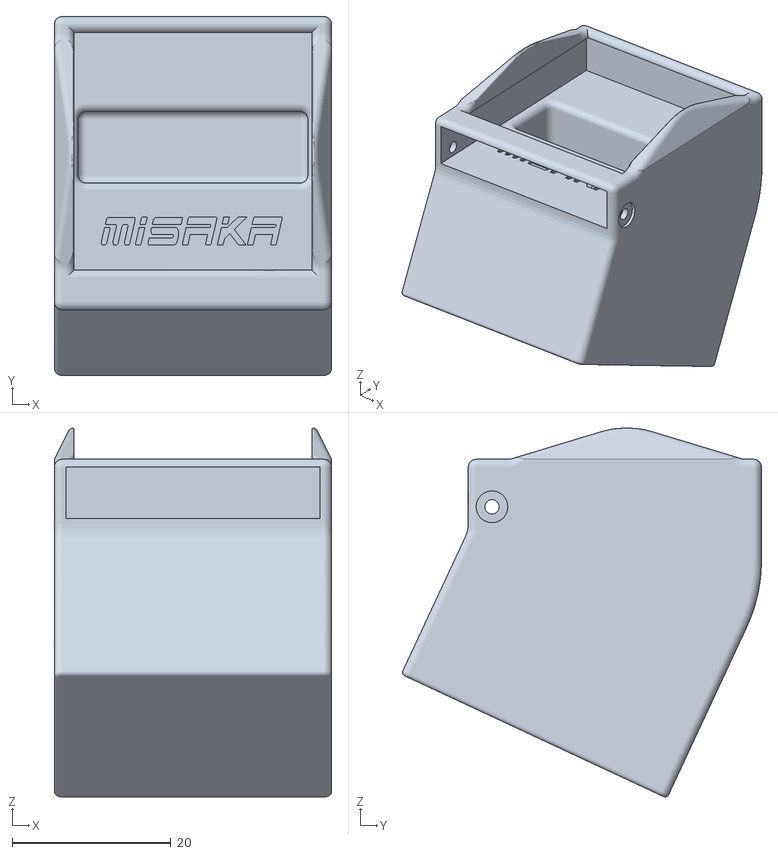
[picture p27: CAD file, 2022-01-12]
4.3D Model/SD3/棱镜版外壳-外壳2.0/棱镜版外壳-外壳2.0.STL
35.0 x 45.3 x 46.5

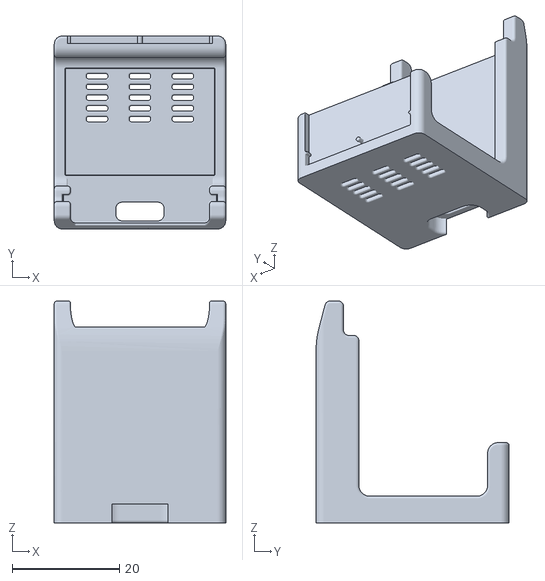
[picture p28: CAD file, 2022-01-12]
4.3D Model/SD2/1.1/后壳1.1.STL
32.0 x 36.0 x 41.4

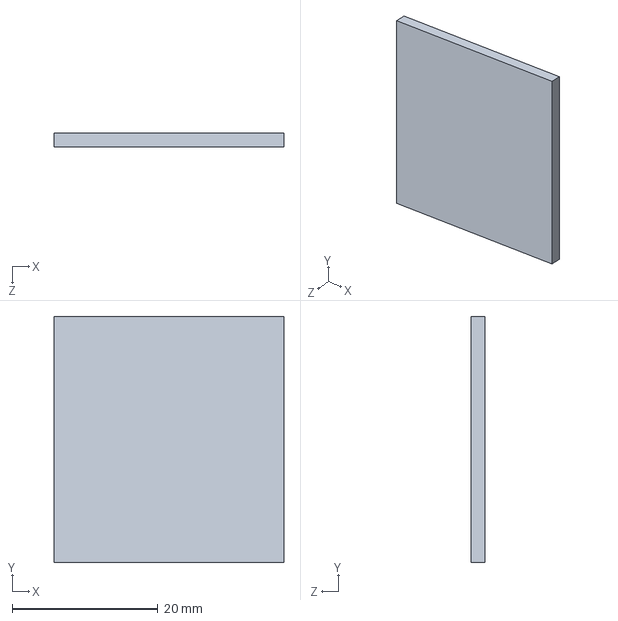
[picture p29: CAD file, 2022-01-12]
4.3D Model/SD3/sw/1.54TFT.SLDPRT
31.5 x 33.7 x 1.90 mm

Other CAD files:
4.3D Model/SD2/SD²外壳1.2版本step文件/主体1.2.STEP
4.3D Model/SD2/1.2/主体1.2.STL
4.3D Model/SD2/SD²外壳1.2版本step文件/后壳1.2.STEP
4.3D Model/SD3/SD³外壳1.1版本step文件/内壳.STEP
4.3D Model/SD3/外壳3D文件（推荐）/外壳V1.1.STL
4.3D Model/SD3/sw/内壳.SLDPRT

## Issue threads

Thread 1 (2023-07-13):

字库问题

SignUpOrNot, 2023-07-13:
你好，我最近在复刻该项目，但是遇到了字库缺字的问题，具体是我所在的城市名称不在字库中。我注意到了《如何制作字库》这个教程，但是用GB2312的3000多个常用字生成的字库编译出来要占2M flash。我先是尝试修改linkscript，让程序正常编译和链接，最后生成的2M bin文件下载到设备上后无法执行。后来了解到ESP8266的程序执行空间IROM在内存的映射中只有1M，也就是说，程序最大只能1M我该链接脚本也无济于事。
最后回到了如何在现有字库上增加少量特殊字的问题，所以想咨询你一下，代码中的ZdyLwFont_20字库是基于那些字生成的，如果可以的话，希望得到你这份字库的所有字符。非常感谢！

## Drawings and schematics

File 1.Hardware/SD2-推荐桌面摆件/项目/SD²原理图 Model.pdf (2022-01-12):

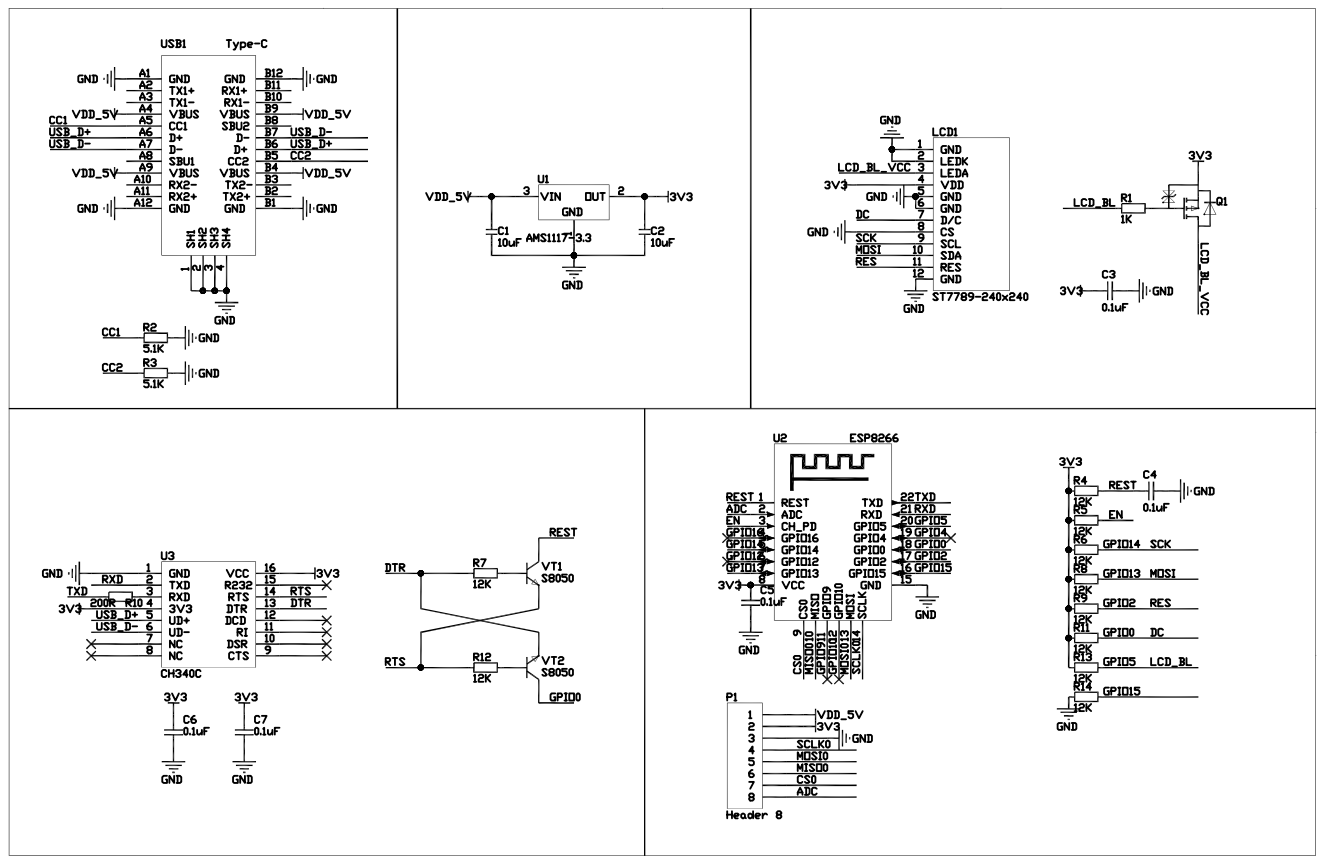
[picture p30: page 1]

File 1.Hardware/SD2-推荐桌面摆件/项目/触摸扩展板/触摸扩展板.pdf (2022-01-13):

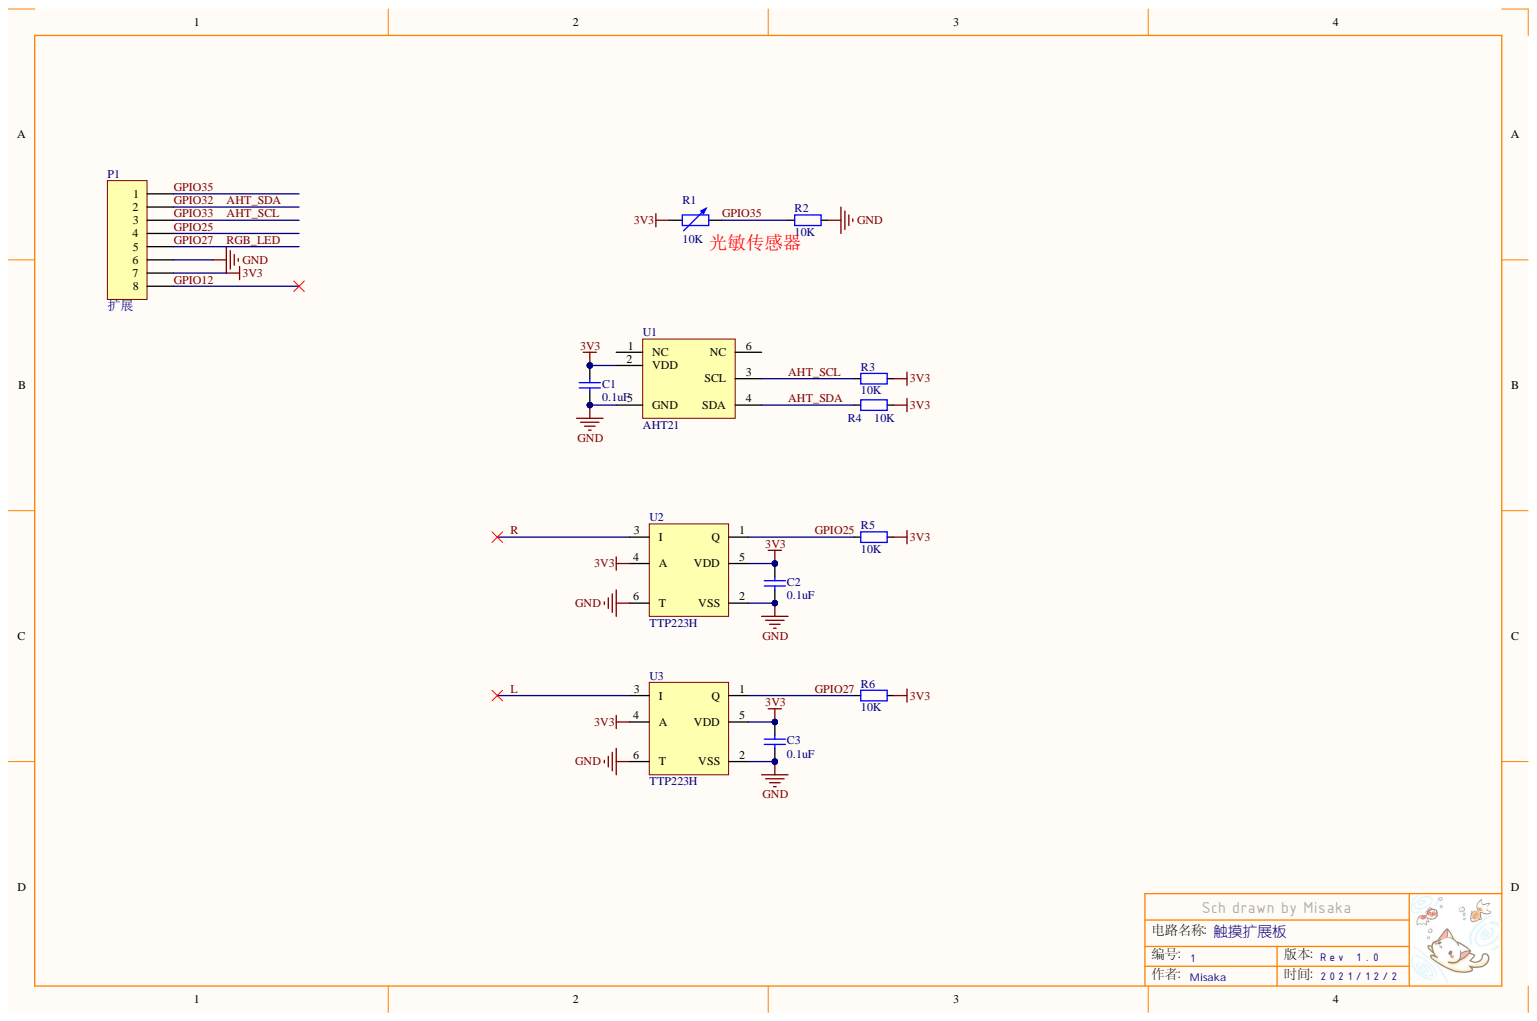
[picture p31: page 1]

编号 : 1 | 版本 : R e v 1 . 0
作者 : Misaka | 时间 : 2 0 2 1 / 1 2 / 2

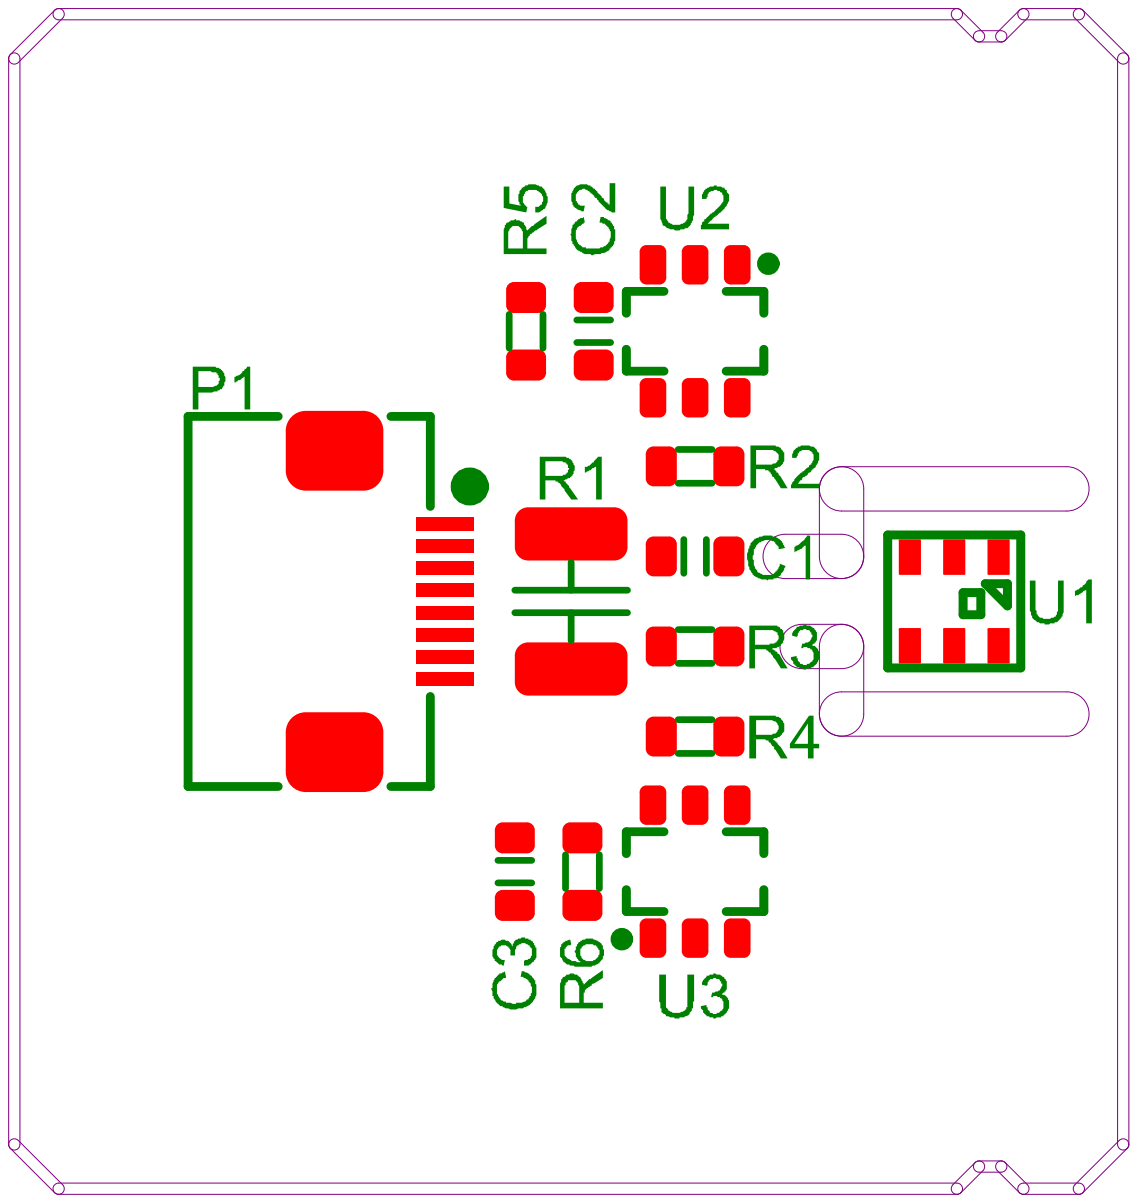
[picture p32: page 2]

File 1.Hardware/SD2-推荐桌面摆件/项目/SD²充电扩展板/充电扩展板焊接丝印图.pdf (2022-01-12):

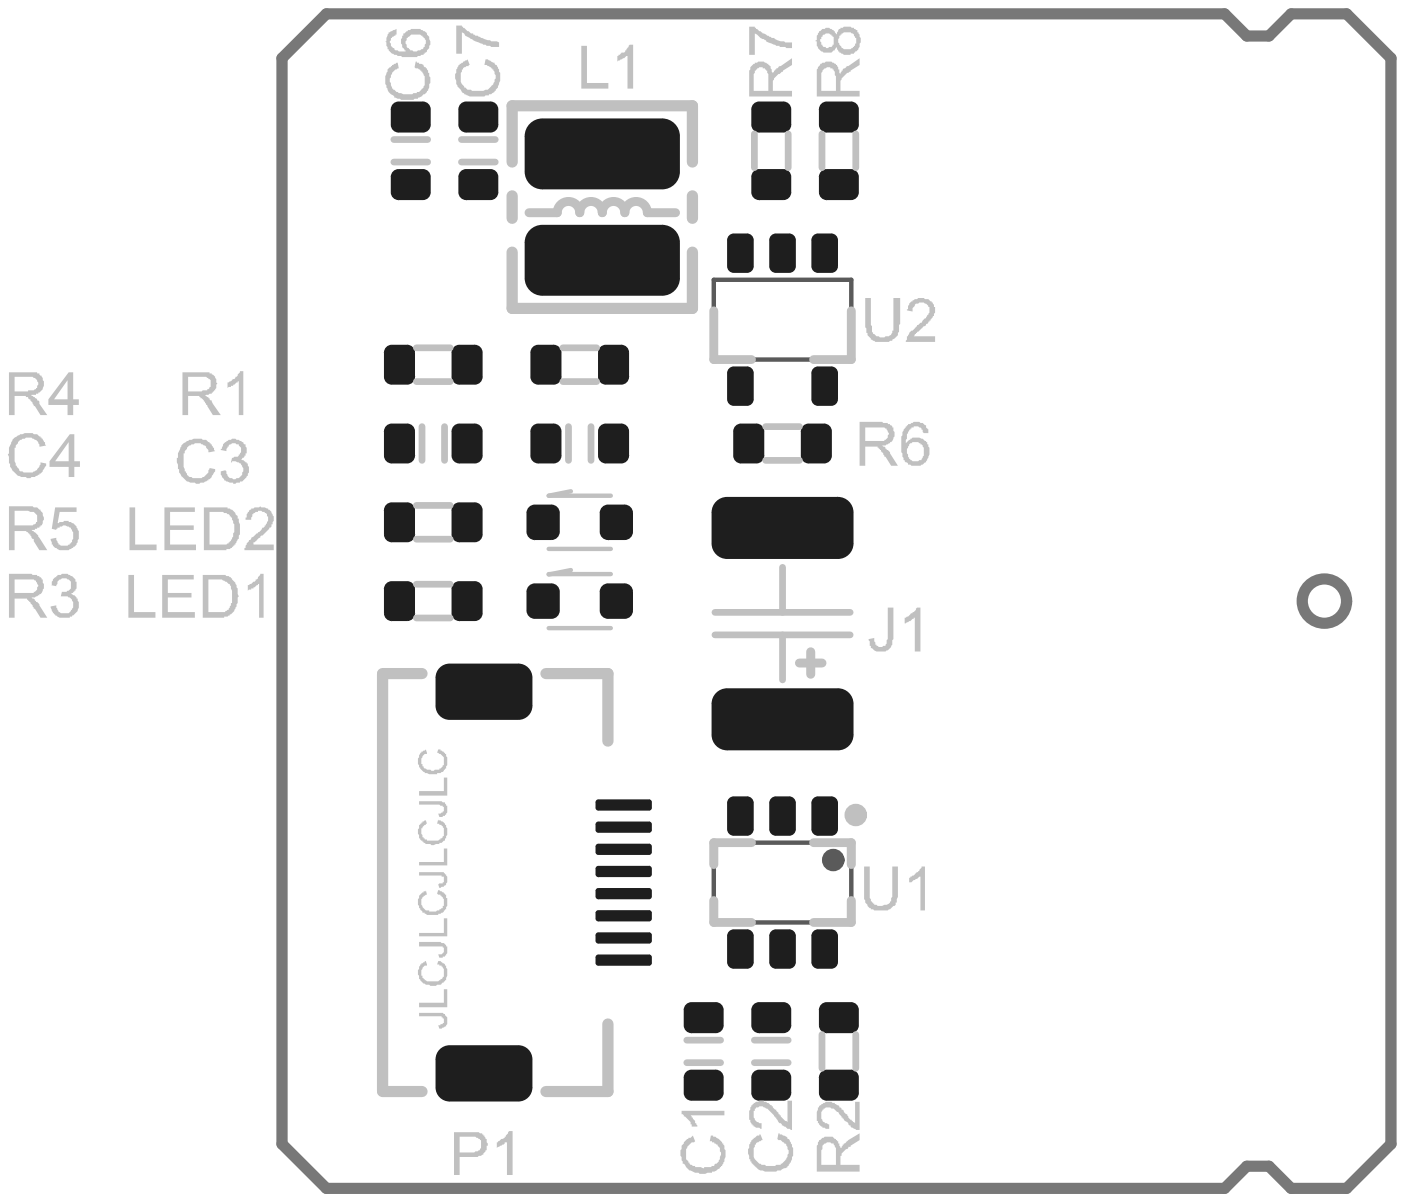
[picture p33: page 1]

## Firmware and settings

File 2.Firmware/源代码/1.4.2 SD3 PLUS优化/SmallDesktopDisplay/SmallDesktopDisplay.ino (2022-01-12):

/* *****************************************************************
 * 
 * SmallDesktopDisplay
 *    小型桌面显示器
 * 测试更改
 * 原  作  者：Misaka
 * 修      改：微车游
 * 再次  修改：丘山鹤
 * 讨  论  群：811058758、887171863、720661626
 * 创 建 日 期：2021.07.19
 * 最后更改日期：2021.11.28
 * 更 改 说 明：V1.1添加串口调试，波特率115200\8\n\1；增加版本号显示。
 *            V1.2亮度和城市代码保存到EEPROM，断电可保存
 *            V1.3.1 更改smartconfig改为WEB配网模式，同时在配网的同时增加亮度、屏幕方向设置。
 *            V1.3.2 增加wifi休眠模式，仅在需要连接的情况下开启wifi，其他时间关闭wifi。增加wifi保存至eeprom（目前仅保存一组ssid和密码）
 *            V1.3.3  修改WiFi保存后无法删除的问题。目前更改为使用串口控制，输入 0x05 重置WiFi数据并重启。
 *                    增加web配网以及串口设置天气更新时间的功能。
 *            V1.3.4  修改web配网页面设置，将wifi设置页面以及其余设置选项放入同一页面中。
 *                    增加web页面设置是否使用DHT传感器。（使能DHT后才可使用）
 *             1.4.2  增加长按SD3 Plus底部按钮重置WiFi
 *                    基本汉化网页配置页面
 * 
 * 引 脚 分 配： SCK  GPIO14
 *             MOSI  GPIO13
 *             RES   GPIO2
 *             DC    GPIO0
 *             LCDBL GPIO5
 *             
 *             增加DHT11温湿度传感器，传感器接口为 GPIO 12
 * 
 *    感谢群友 @你别失望  提醒发现WiFi保存后无法重置的问题，目前已解决。详情查看更改说明！
 * *****************************************************************/

/* *****************************************************************
 *  库文件、头文件
 * *****************************************************************/
#include "ArduinoJson.h"
#include <TimeLib.h>
#include <ESP8266WiFi.h>
#include <ESP8266HTTPClient.h>
#include <ESP8266WebServer.h>
#include <WiFiUdp.h>
#include <TFT_eSPI.h> 
#include <SPI.h>
#include <TJpg_Decoder.h>
#include <EEPROM.h>
#include "qr.h"
#include "number.h"
#include "weathernum.h"
#include <Button2.h>  //按钮库

#define Version  "SDD V1.4.2"
/* *****************************************************************
 *  配置使能位
 * *****************************************************************/
//WEB配网使能标志位----WEB配网打开后会默认关闭smartconfig功能
#define WM_EN   1
//设定DHT11温湿度传感器使能标志
#define DHT_EN  0
//设置太空人图片是否使用
#define imgAst_EN 1


#if WM_EN
#include <WiFiManager.h>
//WiFiManager 参数
WiFiManager wm; // global wm instance
// WiFiManagerParameter custom_field; // global param ( for non blocking w params )
#endif

#if DHT_EN
#include "DHT.h"
#define DHTPIN  12
#define DHTTYPE DHT11
DHT dht(DHTPIN,DHTTYPE);
#endif

//定义按钮引脚
Button2 Button_sw1 = Button2(4); 



/* *****************************************************************
 *  字库、图片库
 * *****************************************************************/
#include "font/ZdyLwFont_20.h"
#include "img/misaka.h"
#include "img/temperature.h"
#include "img/humidity.h"

#if imgAst_EN
#include "img/pangzi/i0.h"
#include "img/pangzi/i1.h"
#include "img/pangzi/i2.h"
#include "img/pangzi/i3.h"
#include "img/pangzi/i4.h"
#include "img/pangzi/i5.h"
#include "img/pangzi/i6.h"
#include "img/pangzi/i7.h"
#include "img/pangzi/i8.h"
#include "img/pangzi/i9.h"

int Anim = 0;           //太空人图标显示指针记录
int AprevTime = 0;      //太空人更新时间记录
#endif



/* *****************************************************************
 *  参数设置
 * *****************************************************************/

struct config_type
{
  char stassid[32];//定义配网得到的WIFI名长度(最大32字节)
  char stapsw[64];//定义配网得到的WIFI密码长度(最大64字节)
};

//---------------修改此处""内的信息--------------------
//如开启WEB配网则可不用设置这里的参数，前一个为wifi ssid，后一个为密码
config_type wificonf ={{""},{""}};

//天气更新时间  X 分钟
int updateweater_time = 10;

//----------------------------------------------------

//LCD屏幕相关设置
TFT_eSPI tft = TFT_eSPI();  // 引脚请自行配置tft_espi库中的 User_Setup.h文件
TFT_eSprite clk = TFT_eSprite(&tft);
#define LCD_BL_PIN 5    //LCD背光引脚
uint16_t bgColor = 0x0000;

//其余状态标志位
int LCD_Rotation = 0;   //LCD屏幕方向
int LCD_BL_PWM = 50;//屏幕亮度0-100，默认50
uint8_t Wifi_en = 1; //wifi状态标志位  1：打开    0：关闭
uint8_t UpdateWeater_en = 0; //更新时间标志位
int prevTime = 0;       //滚动显示更新标志位
int DHT_img_flag = 0;   //DHT传感器使用标志位


time_t prevDisplay = 0;       //显示时间显示记录
unsigned long weaterTime = 0; //天气更新时间记录


/*** Component objects ***/
Number      dig;
WeatherNum  wrat;

uint32_t targetTime = 0;   
String cityCode = "0";  //天气城市代码 长沙:101250101株洲:101250301衡阳:101250401
int tempnum = 0;   //温度百分比
int huminum = 0;   //湿度百分比
int tempcol =0xffff;   //温度显示颜色
int humicol =0xffff;   //湿度显示颜色


//EEPROM参数存储地址位
int BL_addr = 1;//被写入数据的EEPROM地址编号  1亮度
int Ro_addr = 2; //被写入数据的EEPROM地址编号  2 旋转方向
int DHT_addr = 3;//3 DHT使能标志位
int CC_addr = 10;//被写入数据的EEPROM地址编号  10城市
int wifi_addr = 30; //被写入数据的EEPROM地址编号  20wifi-ssid-psw


//NTP服务器参数
static const char ntpServerName[] = "ntp6.aliyun.com";
const int timeZone = 8;     //东八区

//wifi连接UDP设置参数
WiFiUDP Udp;
WiFiClient wificlient;
unsigned int localPort = 8000;
float duty=0;


//函数声明
time_t getNtpTime();
void digitalClockDisplay(int reflash_en);
void printDigits(int digits);
String num2str(int digits);
void sendNTPpacket(IPAddress &address);
void LCD_reflash(int en);
void savewificonfig();
void readwificonfig();
void deletewificonfig();


/* *****************************************************************
 *  函数
 * *****************************************************************/

//wifi ssid，psw保存到eeprom
void savewificonfig()
{
  //开始写入
  uint8_t *p = (uint8_t*)(&wificonf);
  for (int i = 0; i < sizeof(wificonf); i++)
  {
    EEPROM.write(i + wifi_addr, *(p + i)); //在闪存内模拟写入
  }
  delay(10);
  EEPROM.commit();//执行写入ROM
  delay(10);
}
//删除原有eeprom中的信息
void deletewificonfig()
{
  config_type deletewifi ={{""},{""}};
  uint8_t *p = (uint8_t*)(&deletewifi);
  for (int i = 0; i < sizeof(deletewifi); i++)
  {
    EEPROM.write(i + wifi_addr, *(p + i)); //在闪存内模拟写入
  }
  delay(10);
  EEPROM.commit();//执行写入ROM
  delay(10);
}

//从eeprom读取WiFi信息ssid，psw
void readwificonfig()
{
  uint8_t *p = (uint8_t*)(&wificonf);
  for (int i = 0; i < sizeof(wificonf); i++)
  {
    *(p + i) = EEPROM.read(i + wifi_addr);
  }
  // EEPROM.commit();
  // ssid = wificonf.stassid;
  // pass = wificonf.stapsw;
  Serial.printf("Read WiFi Config.....\r\n");
  Serial.printf("SSID:%s\r\n",wificonf.stassid);
  Serial.printf("PSW:%s\r\n",wificonf.stapsw);
  Serial.printf("Connecting.....\r\n");
}

//TFT屏幕输出函数
bool tft_output(int16_t x, int16_t y, uint16_t w, uint16_t h, uint16_t* bitmap)
{
  if ( y >= tft.height() ) return 0;
  tft.pushImage(x, y, w, h, bitmap);
  // Return 1 to decode next block
  return 1;
}

//进度条函数
byte loadNum = 6;
void loading(byte delayTime)//绘制进度条
{
  clk.setColorDepth(8);
  
  clk.createSprite(200, 100);//创建窗口
  clk.fillSprite(0x0000);   //填充率

  clk.drawRoundRect(0,0,200,16,8,0xFFFF);       //空心圆角矩形
  clk.fillRoundRect(3,3,loadNum,10,5,0xFFFF);   //实心圆角矩形
  clk.setTextDatum(CC_DATUM);   //设置文本数据
  clk.setTextColor(TFT_GREEN, 0x0000); 
  clk.drawString("Connecting to WiFi......",100,40,2);
  clk.setTextColor(TFT_WHITE, 0x0000); 
  clk.drawRightString(Version,180,60,2);
  clk.pushSprite(20,120);  //窗口位置
  
  //clk.setTextDatum(CC_DATUM);
  //clk.setTextColor(TFT_WHITE, 0x0000); 
  //clk.pushSprite(130,180);
  
  clk.deleteSprite();
  loadNum += 1;
  delay(delayTime);
}

//湿度图标显示函数
void humidityWin()
{
  clk.setColorDepth(8);
  
  huminum = huminum/2;
  clk.createSprite(52, 6);  //创建窗口
  clk.fillSprite(0x0000);    //填充率
  clk.drawRoundRect(0,0,52,6,3,0xFFFF);  //空心圆角矩形  起始位x,y,长度，宽度，圆弧半径，颜色
  clk.fillRoundRect(1,1,huminum,4,2,humicol);   //实心圆角矩形
  clk.pushSprite(45,222);  //窗口位置
  clk.deleteSprite();
}

//温度图标显示函数
void tempWin()
{
  clk.setColorDepth(8);
  
  clk.createSprite(52, 6);  //创建窗口
  clk.fillSprite(0x0000);    //填充率
  clk.drawRoundRect(0,0,52,6,3,0xFFFF);  //空心圆角矩形  起始位x,y,长度，宽度，圆弧半径，颜色
  clk.fillRoundRect(1,1,tempnum,4,2,tempcol);   //实心圆角矩形
  clk.pushSprite(45,192);  //窗口位置
  clk.deleteSprite();
}

#if DHT_EN
//外接DHT11传感器，显示数据
void IndoorTem()
{
  float t = dht.readTemperature();
  float h = dht.readHumidity();
  String s = "内温";
   /***绘制相关文字***/
  clk.setColorDepth(8);
  clk.loadFont(ZdyLwFont_20);
  
  //位置
  clk.createSprite(58, 30);
  clk.fillSprite(bgColor);
  clk.setTextDatum(CC_DATUM);
  clk.setTextColor(TFT_WHITE, bgColor);
  clk.drawString(s,29,16);
  clk.pushSprite(172,150);
  clk.deleteSprite();
  
  //温度
  clk.createSprite(60, 24); 
  clk.fillSprite(bgColor);
  clk.setTextDatum(CC_DATUM);
  clk.setTextColor(TFT_WHITE, bgColor); 
  clk.drawFloat(t,1,20,13);
//  clk.drawString(sk["temp"].as<String>()+"℃",28,13);
  clk.drawString("℃",50,13);
  clk.pushSprite(170,184);
  clk.deleteSprite();
  
  //湿度
  clk.createSprite(60, 24); 
  clk.fillSprite(bgColor);
  clk.setTextDatum(CC_DATUM);
  clk.setTextColor(TFT_WHITE, bgColor); 
//  clk.drawString(sk["SD"].as<String>(),28,13);
  clk.drawFloat(h,1,20,13);
  clk.drawString("%",50,13);
  //clk.drawString("100%",28,13);
  clk.pushSprite(170,214);
  clk.deleteSprite();
}
#endif

#if !WM_EN
//微信配网函数
void SmartConfig(void)
{
  WiFi.mode(WIFI_STA);    //设置STA模式
  //tft.pushImage(0, 0, 240, 240, qr);
  tft.pushImage(0, 0, 240, 240, qr);
  Serial.println("\r\nWait for Smartconfig...");    //打印log信息
  WiFi.beginSmartConfig();      //开始SmartConfig，等待手机端发出用户名和密码
  while (1)
  {
    Serial.print(".");
    delay(100);                   // wait for a second
    if (WiFi.smartConfigDone())//配网成功，接收到SSID和密码
    {
    Serial.println("SmartConfig Success");
    Serial.printf("SSID:%s\r\n", WiFi.SSID().c_str());
    Serial.printf("PSW:%s\r\n", WiFi.psk().c_str());
    break;
    }
  }
  loadNum = 194;
}
#endif

String SMOD = "";//0亮度
//串口调试设置函数
void Serial_set()
{
  String incomingByte = "";
  if(Serial.available()>0)
  {
    
    while(Serial.available()>0)//监测串口缓存，当有数据输入时，循环赋值给incomingByte
    {
      incomingByte += char(Serial.read());//读取单个字符值，转换为字符，并按顺序一个个赋值给incomingByte
      delay(2);//不能省略，因为读取缓冲区数据需要时间
    }    
    if(SMOD=="0x01")//设置1亮度设置
    {
      int LCDBL = atoi(incomingByte.c_str());//int n = atoi(xxx.c_str());//String转int
      if(LCDBL>=0 && LCDBL<=100)
      {
        EEPROM.write(BL_addr, LCDBL);//亮度地址写入亮度值
        EEPROM.commit();//保存更改的数据
        delay(5);
        LCD_BL_PWM = EEPROM.read(BL_addr); 
        delay(5);
        SMOD = "";
        Serial.printf("亮度调整为：");
        analogWrite(LCD_BL_PIN, 1023 - (LCD_BL_PWM*10));
        Serial.println(LCD_BL_PWM);
        Serial.println("");
      }
      else
        Serial.println("亮度调整错误，请输入0-100");
    } 
    if(SMOD=="0x02")//设置2地址设置
    {
      int CityCODE = 0;
      int CityC = atoi(incomingByte.c_str());//int n = atoi(xxx.c_str());//String转int
      if(CityC>=101000000 && CityC<=102000000 || CityC == 0)
      {
        for(int cnum=0;cnum<5;cnum++)
        {
          EEPROM.write(CC_addr+cnum,CityC%100);//城市地址写入城市代码
          EEPROM.commit();//保存更改的数据
          CityC = CityC/100;
          delay(5);
        }
        for(int cnum=5;cnum>0;cnum--)
        {          
          CityCODE = CityCODE*100;
          CityCODE += EEPROM.read(CC_addr+cnum-1); 
          delay(5);
        }
        
        cityCode = CityCODE;
        
        if(cityCode == "0")
        {
          Serial.println("城市代码调整为：自动");
          getCityCode();  //获取城市代码
        }
        else
        {
          Serial.printf("城市代码调整为：");
          Serial.println(cityCode);
        }
        Serial.println("");
        getCityWeater();//更新城市天气  
        SMOD = "";
      }
      else
        Serial.println("城市调整错误，请输入9位城市代码，自动获取请输入0");
    }   
    if(SMOD=="0x03")//设置3屏幕显示方向
    {
      int RoSet = atoi(incomingByte.c_str());
      if(RoSet >= 0 && RoSet <= 3)
      {
        EEPROM.write(Ro_addr, RoSet);//屏幕方向地址写入方向值
        EEPROM.commit();//保存更改的数据
        SMOD = "";
      //设置屏幕方向后重新刷屏并显示
        tft.setRotation(RoSet);
        tft.fillScreen(0x0000);
        LCD_reflash(1);//屏幕刷新程序
        UpdateWeater_en = 1;
        TJpgDec.drawJpg(15,183,temperature, sizeof(temperature));  //温度图标
        TJpgDec.drawJpg(15,213,humidity, sizeof(humidity));  //湿度图标
        // getCityWeater();
        // digitalClockDisplay(1);
        // scrollBanner();
        // #if DHT_EN
        //   if(DHT_img_flag == 1)
        //   IndoorTem();
        // #endif
        // #if imgAst_EN
        //   if(DHT_img_flag == 0)
        //   imgAnim();
        // #endif


        Serial.print("屏幕方向设置为：");
        Serial.println(RoSet);
      }
      else 
      {
        Serial.println("屏幕方向值错误，请输入0-3内的值");
      }
    }
    if(SMOD=="0x04")//设置天气更新时间
    {
      int wtup = atoi(incomingByte.c_str());//int n = atoi(xxx.c_str());//String转int
      if(wtup>=1 && wtup<=60)
      {
        updateweater_time = wtup;
        SMOD = "";
        Serial.printf("天气更新时间更改为：");
        Serial.print(updateweater_time);
        Serial.println("分钟");
      }
      else
        Serial.println("更新时间太长，请重新设置（1-60）");
    } 
    else
    {
      SMOD = incomingByte;
      delay(2);
      if(SMOD=="0x01")
        Serial.println("请输入亮度值，范围0-100");
      else if(SMOD=="0x02")
        Serial.println("请输入9位城市代码，自动获取请输入0"); 
      else if(SMOD=="0x03")
      {
        Serial.println("请输入屏幕方向值，"); 
        Serial.println("0-USB接口朝下");
        Serial.println("1-USB接口朝右");
        Serial.println("2-USB接口朝上");
        Serial.println("3-USB接口朝左");
      }
      else if(SMOD=="0x04")
      {
        Serial.print("当前天气更新时间："); 
        Serial.print(updateweater_time);
        Serial.println("分钟");
        Serial.println("请输入天气更新时间（1-60）分钟"); 
      }
      else if(SMOD=="0x05")
      {
        Serial.println("重置WiFi设置中......");
        delay(10);
        wm.resetSettings();
        deletewificonfig();
        delay(10);
        Serial.println("重置WiFi成功");
        SMOD = "";
        ESP.restart();
      }
      else
      {
        Serial.println("");
        Serial.println("请输入需要修改的代码：");
        Serial.println("亮度设置输入        0x01");
        Serial.println("地址设置输入        0x02");
        Serial.println("屏幕方向设置输入    0x03");
        Serial.println("更改天气更新时间    0x04");
        Serial.println("重置WiFi(会重启)    0x05");
        Serial.println("");
      }
    }
  }
}
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
void loop()
{
  LCD_reflash(0);
  Serial_set();
  Button_sw1.loop(); //按钮轮询
}

void LCD_reflash(int en)
{
  if (now() != prevDisplay || en == 1) 
  {
    prevDisplay = now();
    digitalClockDisplay(en);
    prevTime=0;  
  }
  
  //两秒钟更新一次
  if(second()%2 ==0&& prevTime == 0 || en == 1){
#if DHT_EN
    if(DHT_img_flag != 0)
    IndoorTem();
#endif
    scrollBanner();
  }
#if imgAst_EN
  if(DHT_img_flag == 0)
  imgAnim();
#endif


  if(millis() - weaterTime > (60000*updateweater_time) || en == 1 || UpdateWeater_en != 0){ //10分钟更新一次天气
    if(Wifi_en == 0)
    {
      WiFi.forceSleepWake();//wifi on
      Serial.println("WIFI恢复......");
      Wifi_en = 1;
    }

    if(WiFi.status() == WL_CONNECTED)
    {
      Serial.println("WIFI已连接");
      getCityWeater();
      if(UpdateWeater_en != 0) UpdateWeater_en = 0;
      weaterTime = millis();
      while(!getNtpTime());
      WiFi.forceSleepBegin(); // Wifi Off
      Serial.println("WIFI休眠......");
      Wifi_en = 0;
    }
  }
}

// 发送HTTP请求并且将服务器响应通过串口输出
void getCityCode(){
 String URL = "http://wgeo.weather.com.cn/ip/?_="+String(now());
  //创建 HTTPClient 对象
  HTTPClient httpClient;
 
  //配置请求地址。此处也可以不使用端口号和PATH而单纯的
  httpClient.begin(wificlient,URL); 
  
  //设置请求头中的User-Agent
  httpClient.setUserAgent("Mozilla/5.0 (iPhone; CPU iPhone OS 11_0 like Mac OS X) AppleWebKit/604.1.38 (KHTML, like Gecko) Version/11.0 Mobile/15A372 Safari/604.1");
  httpClient.addHeader("Referer", "http://www.weather.com.cn/");
 
  //启动连接并发送HTTP请求
  int httpCode = httpClient.GET();
  Serial.print("Send GET request to URL: ");
  Serial.println(URL);
  
  //如果服务器响应OK则从服务器获取响应体信息并通过串口输出
  if (httpCode == HTTP_CODE_OK) {
    String str = httpClient.getString();
    
    int aa = str.indexOf("id=");
    if(aa>-1)
    {
       //cityCode = str.substring(aa+4,aa+4+9).toInt();
       cityCode = str.substring(aa+4,aa+4+9);
       Serial.println(cityCode); 
       getCityWeater();
    }
    else
    {
      Serial.println("获取城市代码失败");  
    }
    
    
  } else {
    Serial.println("请求城市代码错误：");
    Serial.println(httpCode);
  }
 
  //关闭ESP8266与服务器连接
  httpClient.end();
}



// 获取城市天气
void getCityWeater(){
 //String URL = "http://d1.weather.com.cn/dingzhi/" + cityCode + ".html?_="+String(now());//新
 String URL = "http://d1.weather.com.cn/weather_index/" + cityCode + ".html?_="+String(now());//原来
  //创建 HTTPClient 对象
  HTTPClient httpClient;
  
  httpClient.begin(URL); 
  
  //设置请求头中的User-Agent
  httpClient.setUserAgent("Mozilla/5.0 (iPhone; CPU iPhone OS 11_0 like Mac OS X) AppleWebKit/604.1.38 (KHTML, like Gecko) Version/11.0 Mobile/15A372 Safari/604.1");
  httpClient.addHeader("Referer", "http://www.weather.com.cn/");
 
  //启动连接并发送HTTP请求
  int httpCode = httpClient.GET();
  Serial.println("正在获取天气数据");
  Serial.println(URL);
  
  //如果服务器响应OK则从服务器获取响应体信息并通过串口输出
  if (httpCode == HTTP_CODE_OK) {

    String str = httpClient.getString();
    int indexStart = str.indexOf("weatherinfo\":");
    int indexEnd = str.indexOf("};var alarmDZ");

    String jsonCityDZ = str.substring(indexStart+13,indexEnd);
    //Serial.println(jsonCityDZ);

    indexStart = str.indexOf("dataSK =");
    indexEnd = str.indexOf(";var dataZS");
    String jsonDataSK = str.substring(indexStart+8,indexEnd);
    //Serial.println(jsonDataSK);

    
    indexStart = str.indexOf("\"f\":[");
    indexEnd = str.indexOf(",{\"fa");
    String jsonFC = str.substring(indexStart+5,indexEnd);
    //Serial.println(jsonFC);
    
    weaterData(&jsonCityDZ,&jsonDataSK,&jsonFC);
    Serial.println("获取成功");
    
  } else {
    Serial.println("请求城市天气错误：");
    Serial.print(httpCode);
  }
 
  //关闭ESP8266与服务器连接
  httpClient.end();
}


String scrollText[7];
//int scrollTextWidth = 0;
//天气信息写到屏幕上
void weaterData(String *cityDZ,String *dataSK,String *dataFC)
{
  //解析第一段JSON
  DynamicJsonDocument doc(1024);
  deserializeJson(doc, *dataSK);
  JsonObject sk = doc.as<JsonObject>();

  //TFT_eSprite clkb = TFT_eSprite(&tft);
  
  /***绘制相关文字***/
  clk.setColorDepth(8);
  clk.loadFont(ZdyLwFont_20);
  
  //温度
  clk.createSprite(58, 24); 
  clk.fillSprite(bgColor);
  clk.setTextDatum(CC_DATUM);
  clk.setTextColor(TFT_WHITE, bgColor); 
  clk.drawString(sk["temp"].as<String>()+"℃",28,13);
  clk.pushSprite(100,184);
  clk.deleteSprite();
  tempnum = sk["temp"].as<int>();
  tempnum = tempnum+10;
  if(tempnum<10)
    tempcol=0x00FF;
  else if(tempnum<28)
    tempcol=0x0AFF;
  else if(tempnum<34)
    tempcol=0x0F0F;
  else if(tempnum<41)
    tempcol=0xFF0F;
  else if(tempnum<49)
    tempcol=0xF00F;
  else
  {
    tempcol=0xF00F;
    tempnum=50;
  }
  tempWin();
  
  //湿度
  clk.createSprite(58, 24); 
  clk.fillSprite(bgColor);
  clk.setTextDatum(CC_DATUM);
  clk.setTextColor(TFT_WHITE, bgColor); 
  clk.drawString(sk["SD"].as<String>(),28,13);
  //clk.drawString("100%",28,13);
  clk.pushSprite(100,214);
  clk.deleteSprite();
  //String A = sk["SD"].as<String>();
  huminum = atoi((sk["SD"].as<String>()).substring(0,2).c_str());
  
  if(huminum>90)
    humicol=0x00FF;
  else if(huminum>70)
    humicol=0x0AFF;
  else if(huminum>40)
    humicol=0x0F0F;
  else if(huminum>20)
    humicol=0xFF0F;
  else
    humicol=0xF00F;
  humidityWin();

  
  //城市名称
  clk.createSprite(94, 30); 
  clk.fillSprite(bgColor);
  clk.setTextDatum(CC_DATUM);
  clk.setTextColor(TFT_WHITE, bgColor); 
  clk.drawString(sk["cityname"].as<String>(),44,16);
  clk.pushSprite(15,15);
  clk.deleteSprite();

  //PM2.5空气指数
  uint16_t pm25BgColor = tft.color565(156,202,127);//优
  String aqiTxt = "优";
  int pm25V = sk["aqi"];
  if(pm25V>200){
    pm25BgColor = tft.color565(136,11,32);//重度
    aqiTxt = "重度";
  }else if(pm25V>150){
    pm25BgColor = tft.color565(186,55,121);//中度
    aqiTxt = "中度";
  }else if(pm25V>100){
    pm25BgColor = tft.color565(242,159,57);//轻
    aqiTxt = "轻度";
  }else if(pm25V>50){
    pm25BgColor = tft.color565(247,219,100);//良
    aqiTxt = "良";
  }
  clk.createSprite(56, 24); 
  clk.fillSprite(bgColor);
  clk.fillRoundRect(0,0,50,24,4,pm25BgColor);
  clk.setTextDatum(CC_DATUM);
  clk.setTextColor(0x0000); 
  clk.drawString(aqiTxt,25,13);
  clk.pushSprite(104,18);
  clk.deleteSprite();
  
  scrollText[0] = "实时天气 "+sk["weather"].as<String>();
  scrollText[1] = "空气质量 "+aqiTxt;
  scrollText[2] = "风向 "+sk["WD"].as<String>()+sk["WS"].as<String>();

  //scrollText[6] = atoi((sk["weathercode"].as<String>()).substring(1,3).c_str()) ;

  //天气图标
  wrat.printfweather(170,15,atoi((sk["weathercode"].as<String>()).substring(1,3).c_str()));

  
  //左上角滚动字幕
  //解析第二段JSON
  deserializeJson(doc, *cityDZ);
  JsonObject dz = doc.as<JsonObject>();
  //Serial.println(sk["ws"].as<String>());
  //横向滚动方式
  //String aa = "今日天气:" + dz["weather"].as<String>() + "，温度:最低" + dz["tempn"].as<String>() + "，最高" + dz["temp"].as<String>() + " 空气质量:" + aqiTxt + "，风向:" + dz["wd"].as<String>() + dz["ws"].as<String>();
  //scrollTextWidth = clk.textWidth(scrollText);
  //Serial.println(aa);
  scrollText[3] = "今日"+dz["weather"].as<String>();
  
  deserializeJson(doc, *dataFC);
  JsonObject fc = doc.as<JsonObject>();
  
  scrollText[4] = "最低温度"+fc["fd"].as<String>()+"℃";
  scrollText[5] = "最高温度"+fc["fc"].as<String>()+"℃";
  
  //Serial.println(scrollText[0]);
  
  clk.unloadFont();
}

int currentIndex = 0;
TFT_eSprite clkb = TFT_eSprite(&tft);

void scrollBanner(){
  //if(millis() - prevTime > 2333) //3秒切换一次
//  if(second()%2 ==0&& prevTime == 0)
//  { 
    if(scrollText[currentIndex])
    {
      clkb.setColorDepth(8);
      clkb.loadFont(ZdyLwFont_20);
      clkb.createSprite(150, 30); 
      clkb.fillSprite(bgColor);
      clkb.setTextWrap(false);
      clkb.setTextDatum(CC_DATUM);
      clkb.setTextColor(TFT_WHITE, bgColor); 
      clkb.drawString(scrollText[currentIndex],74, 16);
      clkb.pushSprite(10,45);
       
      clkb.deleteSprite();
      clkb.unloadFont();
      
      if(currentIndex>=5)
        currentIndex = 0;  //回第一个
      else
        currentIndex += 1;  //准备切换到下一个        
    }
    prevTime = 1;
//  }
}
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

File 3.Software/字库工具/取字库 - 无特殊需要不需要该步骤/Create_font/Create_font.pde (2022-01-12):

// This is a Processing sketch, see https://processing.org/ to download the IDE

// Select the font, size and character ranges in the user configuration section
// of this sketch, which starts at line 120. Instructions start at line 50.


/*
Software License Agreement (FreeBSD License)
 
 Copyright (c) 2018 Bodmer (https://github.com/Bodmer)
 
 All rights reserved.
 
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
 1. Redistributions of source code must retain the above copyright notice, this
 list of conditions and the following disclaimer.
 2. Redistributions in binary form must reproduce the above copyright notice,
 this list of conditions and the following disclaimer in the documentation
 and/or other materials provided with the distribution.
 
 THIS SOFTWARE IS PROVIDED BY THE COPYRIGHT HOLDERS AND CONTRIBUTORS "AS IS" AND
 ANY EXPRESS OR IMPLIED WARRANTIES, INCLUDING, BUT NOT LIMITED TO, THE IMPLIED
 WARRANTIES OF MERCHANTABILITY AND FITNESS FOR A PARTICULAR PURPOSE ARE
 DISCLAIMED. IN NO EVENT SHALL THE COPYRIGHT OWNER OR CONTRIBUTORS BE LIABLE FOR
 ANY DIRECT, INDIRECT, INCIDENTAL, SPECIAL, EXEMPLARY, OR CONSEQUENTIAL DAMAGES
 (INCLUDING, BUT NOT LIMITED TO, PROCUREMENT OF SUBSTITUTE GOODS OR SERVICES;
 LOSS OF USE, DATA, OR PROFITS; OR BUSINESS INTERRUPTION) HOWEVER CAUSED AND
 ON ANY THEORY OF LIABILITY, WHETHER IN CONTRACT, STRICT LIABILITY, OR TORT
 (INCLUDING NEGLIGENCE OR OTHERWISE) ARISING IN ANY WAY OUT OF THE USE OF THIS
 SOFTWARE, EVEN IF ADVISED OF THE POSSIBILITY OF SUCH DAMAGE.
 
 The views and conclusions contained in the software and documentation are those
 of the authors and should not be interpreted as representing official policies,
 either expressed or implied, of the FreeBSD Project.
 */

////////////////////////////////////////////////////////////////////////////////////////////////

// This is a processing sketch to create font files for the TFT_eSPI library:

// https://github.com/Bodmer/TFT_eSPI

// Coded by Bodmer January 2018, updated 10/2/19
// Version 0.8

// >>>>>>>>>>>>>>>>>>>>             INSTRUCTIONS             <<<<<<<<<<<<<<<<<<<<

// See comments below in code for specifying the font parameters (point size,
// unicode blocks to include etc). Ranges of characters (glyphs) and specific
// individual glyphs can be included in the created "*.vlw" font file.

// Created fonts are saved in the sketches "FontFiles" folder. Press Ctrl+K to
// see that folder location.

// 16 bit Unicode point codes in the range 0x0000 - 0xFFFF are supported.
// Codes 0-31 are control codes such as "tab" and "carraige return" etc.
// and 32 is a "space", these should NOT be included.

// The sketch will convert True Type (a .ttf or .otf file) file stored in the
// sketches "Data" folder as well as your computers' system fonts.

// To maximise rendering performance and the memory consumed only include the characters
// you will use. Characters at the start of the file will render faster than those at
// the end due to the buffering and file seeking overhead.

// The inclusion of "non-existant" characters in a font may give unpredicatable results
// when rendering with the TFT_eSPI library. The Processing sketch window that pops up
// to show the font characters will print "boxes" (also known as Tofu!) for non existant
// characters.

// Once created the files must be loaded into the ESP32 or ESP8266 SPIFFS memory
// using the Arduino IDE plugin detailed here:
// https://github.com/esp8266/arduino-esp8266fs-plugin
// https://github.com/me-no-dev/arduino-esp32fs-plugin

// When the sketch is run it will generate a file called "System_Font_List.txt" in the
// sketch "FontFiles" folder, press Ctrl+K to see it. Open the file in a text editor to
// view it. This list provides the font reference number needed below to locate that
// font on your system.

// The sketch also lists all the available system fonts to the console, you can increase
// the console line count (in preferences.txt) to stop some fonts scrolling out of view.
// See link in File>Preferences to locate "preferences.txt" file. You must close
// Processing then edit the file lines. If Processing is not closed first then the
// edits will be overwritten by defaults! Edit "preferences.txt" as follows for
// 3000 lines, then save, then run Processing again:

//     console.length=3000;             // Line 4 in file
//     console.scrollback.lines=3000;   // Line 7 in file


// Useful links:
/*

 https://en.wikipedia.org/wiki/Unicode_font
 
 https://www.gnu.org/software/freefont/
 https://www.gnu.org/software/freefont/sources/
 https://www.gnu.org/software/freefont/ranges/
 http://savannah.gnu.org/projects/freefont/
 
 http://www.google.com/get/noto/
 
 https://github.com/Bodmer/TFT_eSPI
 https://github.com/esp8266/arduino-esp8266fs-plugin
 https://github.com/me-no-dev/arduino-esp32fs-plugin
 
   >>>>>>>>>>>>>>>>>>>>         END OF INSTRUCTIONS         <<<<<<<<<<<<<<<<<<<< */


import java.awt.Desktop; // Required to allow sketch to open file windows


////////////////////////////////////////////////////////////////////////////////////////////////

//                       >>>>>>>>>> USER CONFIGURED PARAMETERS START HERE <<<<<<<<<<

// Use font number or name, -1 for fontNumber means use fontName below, a value >=0 means use system font number from list.
// When the sketch is run it will generate a file called "systemFontList.txt" in the sketch folder, press Ctrl+K to see it.
// Open the "systemFontList.txt" in a text editor to view the font files and reference numbers for your system.

int fontNumber = -1; // << Use [Number] in brackets from the fonts listed.

// OR use font name for ttf files placed in the "Data" folder or the font number seen in IDE Console for system fonts
//                                                  the font numbers are listed when the sketch is run.
//                |         1         2     |       Maximum filename size for SPIFFS is 31 including leading /
//                 1234567890123456789012345        and added point size and .vlw extension, so max is 25
String fontName = "16 - simhei";  // Manually crop the filename length later after creation if needed
                                     // Note: SPIFFS does NOT accept underscore in a filename!
String fontType = ".ttf";
//String fontType = ".otf";


// Define the font size in points for the TFT_eSPI font file
int  fontSize = 20;

// Font size to use in the Processing sketch display window that pops up (can be different to above)
int displayFontSize = 28;

///////////////////////////////////////////////////////////////////////////////////////////////////////////////////////////
// Next we specify which unicode blocks from the the Basic Multilingual Plane (BMP) are included in the final font file. //
// Note: The ttf/otf font file MAY NOT contain all possible Unicode characters, refer to the fonts online documentation. //
///////////////////////////////////////////////////////////////////////////////////////////////////////////////////////////
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

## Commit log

2022-01-12 SmallDesktopDisplay 创建
    上传项目
    [1.54TFT.SLDPRT, SDDD.PrjPcb, SDDD.SchDoc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]
2022-01-12 测试更改
2022-01-12 添加烧录bin文件软件
2022-01-13 新增触摸扩展板
    [触摸扩展板.PcbDoc, 触摸扩展板.PrjPcb, 触摸扩展板.SchDoc]
